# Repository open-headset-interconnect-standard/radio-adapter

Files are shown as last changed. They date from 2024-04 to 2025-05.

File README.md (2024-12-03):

# Open Source OHIS Radio Adapter(s?)
An open-source OHIS Radio Adapter.

As of 2024-07-17, this is a Work In Progress.

# Goals

1. Design a set of circuits that can be used to build OHIS compliant radio adapters.
2. Designs should be as simple as possible, but no simpler.
3. When laying out boards, keep as many parts through-hole as possible for ease of assembly.
4. There are two types of designs here:
    1. **General:** Has all the circuits required to work with any radio, that needs to be configured.
    2. **Radio Specific:** Trades Configurability for Simplicity.  Make a simpler device for a specific radio.

# Directory Structure

All KiCAD projects are in their own subdirectories off the git root.  Where it makes sense to do so, an additional layer of subdirectory may be used to group several projects together more obviously.

`/Documentation/` and `/docs/` are reserved for documentation source, and documentation output, respectively.

Everything in `/docs/` will be published on github Pages.

## Icom, Yaesu, Kenwood

As of 2024-04-04, I (@SmittyHalibut, Mark Smith, N6MTS) have submitted three schematics (only!) for VERY SIMPLE radio controllers for the Big Three.  A few notes about these:

* **I HAVE NOT TESTED THEM!**  There's no guaranty that they'll work, or even that they won't blow up your radio.  (It most likely won't blow up your radio. Probably.  I think.  It might.  It shouldn't.  Yeah, probably not.  But there's no telling.)
    * If you find a better way to do any of this, please submit a Pull Request, or at least an Issue with your idea.
* **YOU HAVE TO VERIFY PINOUTS MATCH YOUR RADIO!**  I've selected pinouts for most modern versions of these radios, but while researching this, it becomes obvious that older radios were not so consistent, even within a given manufacturer.  (Yaesu seems to be the worst at this, but they all do it.)
    * See [EB3GKE's Mic Pinout Reference](Yaesu/EB3GKE Mic Pinout Reference.pdf), it collects a lot of pinout information.  **BUT THEY GET RJ45 PINOUTS WRONG**.  As far as I could see, all (only most?) of their RJ45 pictures number pins 1 through 8 backwards.  OHIS's schematics are absolutely correct (verified against TIA-568 documents), so if the pinout for your radio looks VERY DIFFERENT than OHIS's pinouts, try reversing the pin numbers and see if thats closer.
* As of 2024-04-04, I've only done the schematics, and even then it's little more than throwing notes down "on paper."  I tried to cover:
    * Connector pinouts (see above).
    * Any electrical circuits required (mostly converting from OHIS's electret level to dynamic level for radios that want dynamic.)

As of 2024-04-25, I (still @SmittyHalibut) laid out the boards described above and had them fabricated.

* **I STILL HAVE NOT TESTED THEM!**

As of 2024-07-17, I (still me) am chatting with @gx1400 about this.  I'm going to send him some of the boards I ordered back in April and he'll help me test.

As of 2024-12-03, I (STILL me) am sending hardware to @gx1400 and a few others for testing.  These tests are covering:

* Yaesu:
  * :check: RJ45 8p8c
  * :check: RJ14 6p6c
  * :green_square: GX16
* Icom:
  * :green_square: RJ45 8p8c
  * :check: GX16
* Kenwood:
  * :check: RJ45 8p8c
  * :check: GX16

If you can test Yaesu GX16 or Icom RJ45, please reach out to me.  @SmittyHalibut on github, or on Discord.

# Parts

Electrical components, in recommended order of assembly:
* 1x 2x2 pin header right angle
* 1x 2x4 pin header right angle
* 1x 1k axial resistor
* 1x 6.2k axial resistor
* 2x 100R axial resistors
* 2x 10uF
* 1x 1k pot
* 1x 5381 (RJ45 with LED) for OHIS socket

Mechanical components, same as User kit:
* 4x M3 6mm screw
* 4x M3 10mm screw
* 4x M3 14mm brass stand-off
* 4x M3 3mm ABS stand-off
* 5x .1" jumper

PCBs in this repo:
* 2x Top-bottom panels
* 1x Main board
* 1x Shim board

Radio Specific parts, in recommended order of assembly:
* 1x Radio Specific Board
* 1x 3.5mm TRRS "headphone/speaker" connector
* Microphone connector.  Either one of:
  * 5380 (RJ45 with no LED) or 5381 (with LED) if its easier, but the LEDs aren't used.
  * GX16 connector, and GX16 riser board

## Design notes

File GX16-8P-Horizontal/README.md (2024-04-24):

# GX16-8P-Horizontal
A small board that allows the mounting of GX16-8P "8 pin round mic connectors" horizontally instead of vertically.

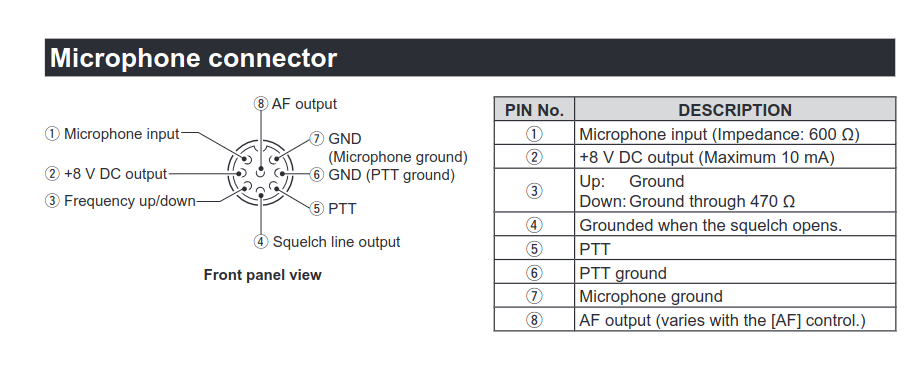
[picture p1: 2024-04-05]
Icom-GX16/Icom GX16-8p pinout.png

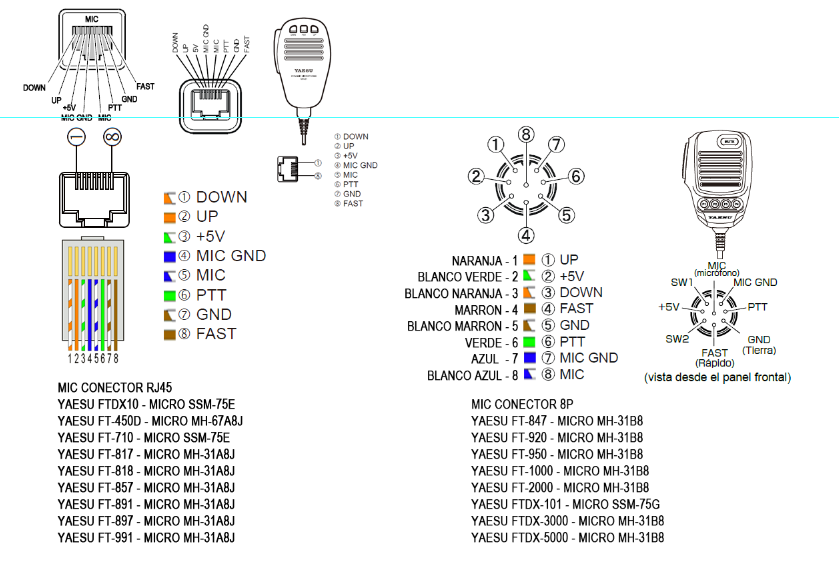
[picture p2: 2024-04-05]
Yaesu-RJ45/MicPinouts.png

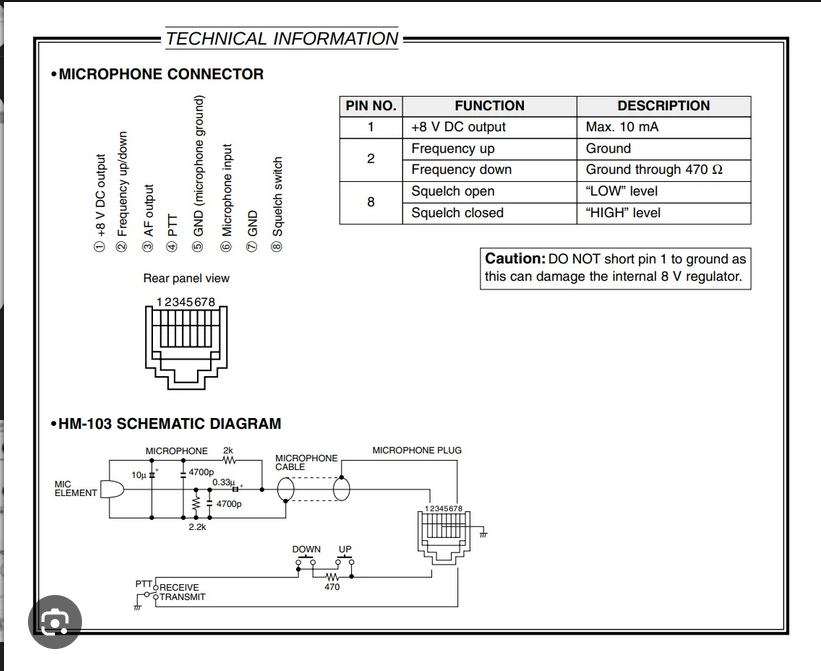
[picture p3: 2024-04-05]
Icom-RJ45/Icom RJ45 pinout.png

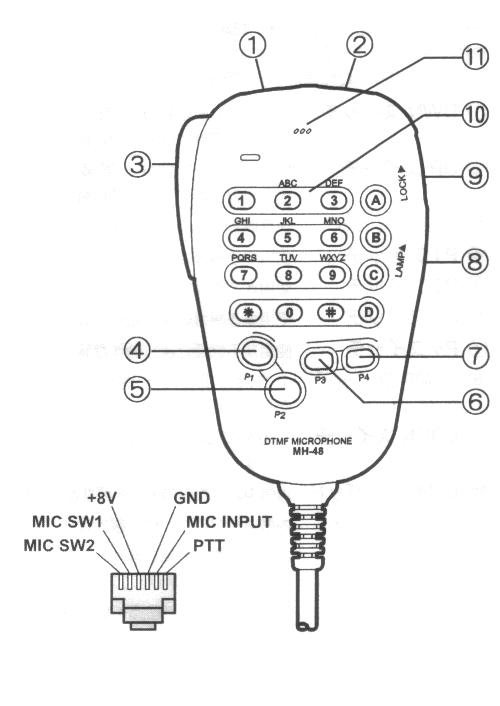
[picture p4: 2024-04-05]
Yaesu-6p6c/MH-48A6JA-1.jpg

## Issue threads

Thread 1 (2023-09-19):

Design Open Source Radio Adapter

SmittyHalibut, 2023-09-19:
Design a simple schematic and board layout for a generic Radio adapter that can be configured by the builder at build time for various different radios.

Keep it simple, make it a good DIY project.

CC-BY, credit to OHIS.  But allow commercial use and extension (read: not -NC and not -SA)

SmittyHalibut, 2024-04-04:
https://github.com/open-headset-interconnect-standard/radio-adapter

SmittyHalibut, 2024-04-18:
Started working on the board for Icom today (the simplest of the boards.)

I went down the SMT/Heatshrink path today, and I'm not happy where that ended up.  Instead, I think I'm going to go down a similar path that I did with https://github.com/open-headset-interconnect-standard/user-adapter/issues/1  where everything is throughhole, and physical construction is a stack of boards, and configuration is done with horizontal jumpers out the side of the stack.  (But it's dinner time now, so later...)

SmittyHalibut, 2024-04-22:
I got the Icom Radio Controller done sorta like the user adapter, then started working on the Kenwood.  While doing so, I realized that all the Radio Adapters are going to have, or not have, the same basic building blocks: mic interface for electret vs dynamic, speaker vs headphone, stereo vs mono.  The main difference between the different radios is the connector and pinout.

Rather than implement these building blocks multiple times on different boards for each manufacturer, I should put all the building blocks on a common board, make them jumper configurable, then make a separate board that just has the physical connections, and routes the pins to the correct signal.  The interface between the two boards is spec'd for the signals, not the pins.

So, that's what I started doing.  See commit 0f612d360049099635a8422bd952ba6b0dee2bb7

This is still very much a work in progress; I have to break to do some other things this week, but will get back to this.

SmittyHalibut, 2024-04-25:
I ordered prototype boards yesterday:
* Base Board
* Radio boards for:
  * Yaesu RJ45, GX16, and RJ12/6p6c (for Yaesu mobiles)
  * Kenwood RJ45, and GX16
  * Icom RJ45, and GX16
* GX16 riser board (to make it a right-angle connector)
* Top/Bottom panels

SmittyHalibut, 2024-12-03:
FINALLY got around to building some of these, and sending kits out to others to test.  I've already found some things I want to do differently.  See #2.

For now, I'll close this ticket and do all follow-up in #2.

Closed 2024-12-03.

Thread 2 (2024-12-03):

Changes for v1.1

SmittyHalibut, 2024-12-03:
Follow-up from #1 these are the changes I want to make.

ATLombardi, 2024-12-07:
I'm not sure how difficult this would be, but with how much clearance is underneath the GX16 it might be possible to lower it down and get away with using the existing standoffs. That might make connecting it to the radio board a little trickier though, since going down much further would put GX16 pin 4 very close to the radio board. Since the connection from pin 4 to the vertical slot is straight down anyway, that might not be a big issue...

ATLombardi, 2024-12-07:
As for the overall layout, I think it'd be interesting to do a version with a female GX16 socket and design the whole adapter to sit almost flush with the radio itself, similar to the PowerPole conversion blocks I've seen for the Yaesu FT-891 and other radios. I know the obvious issue here is that every radio has their mic port in a different place, but fewer cables means a neater setup and fewer things to forget when going portable or helping with an event.

SmittyHalibut, 2024-12-09:
> I'm not sure how difficult this would be, but with how much clearance is underneath the GX16 it might be possible to lower it down and get away with using the existing standoffs. That might make connecting it to the radio board a little trickier though, since going down much further would put GX16 pin 4 very close to the radio board. Since the connection from pin 4 to the vertical slot is straight down anyway, that might not be a big issue...

The vertical space is the concern. I lowered the GX16 as much as was convenient at the time not thinking about this problem. I'll spend some time lowering it as much as possible instead of as convenient. See what I can do.

SmittyHalibut, 2024-12-09:
> As for the overall layout, I think it'd be interesting to do a version with a female GX16 socket and design the whole adapter to sit almost flush with the radio itself, similar to the PowerPole conversion blocks I've seen for the Yaesu FT-891 and other radios. I know the obvious issue here is that every radio has their mic port in a different place, but fewer cables means a neater setup and fewer things to forget when going portable or helping with an event.

That is an interesting idea. I like it. My immediate questions are: I don't think PCB mount GX16s are common, or possibly available at all. I don't REMEMBER seeing them, but I also wasn't looking for them so maybe they are. Have you looked?

I'd also worry about the headphone/speaker connection. Physical spacing between the GX16 and 3.5mm won't be consistent across radios, so the 3.5mm will still need to be a cable for radios that don't provide audio out through the mic port.

But if we can find PCB mount female GX16, that would work pretty well for Icom radios (which do provide receive audio on the GX16.)

gx1400, 2024-12-17:
**Icom GX16 Radio Adapter notes**
Tested with an Icom IC7300 with a Heil Pro Set Elite-Ic (electret) headset.

- No issues with PTT

- Audio is brought in through the GX16, but without a cable plugged into the PHONES port on the front of an ICOM, the IC7300 speaker will not disable.

- Audio coming in through the 3.5mm audio jack is attenuated relative to the audio from the GX16 port (with no audio cable plugged into the GX16 adapter board.
    - I think the R6/R8 resistors are only needed if using GX16 audio? The IC7300 PHONE board has the 100ohm resistors inside the IC7300.

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

I'm confused a bit by the layout. Some install notes could be handy. This layout for the radio base board might need to be reviewed.

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

- Standoff notes
    - Radio adapter PCB screws with the hex standoff spacing.  I replaced the M3x10 mm screw with an M3x12 mm screw and added an M3 nut to adjust the offset a little bit.  Suggest some PCB spacers.
    - The spacers are overall too short. I used 20mm long M3 hex spacers. 18mm would probably work well.

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

- I did not think to remove the nut from the connector.  Suggest notes to do so.
- Schematic shows red X over R7 and R5, but the PCB has those two ref des on the silk screen.  Suggest moving the rest X or change the ref des
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

gx1400, 2024-12-17:
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

Maybe an Icom specific configured board should have some of the following notes:

- Do not install: C1, C2, RV2, R4
- Install jumper wire on J3 from pin 2 to pin 4
- Unsure about R7 & R5 on headphones

SmittyHalibut, 2024-12-17:
> Audio is brought in through the GX16, but without a cable plugged into the PHONES port on the front of an ICOM, the IC7300 speaker will not disable.

This is a known issue.  I'm not sure whether the built-in speaker can be disabled in software while still allowing audio out the GX16.  It might require a dummy-plug in the headphones port or something.

> Audio coming in through the 3.5mm audio jack is attenuated relative to the audio from the GX16 port (with no audio cable plugged into the GX16 adapter board. I think the R6/R8 resistors are only needed if using GX16 audio? The IC7300 PHONE board has the 100ohm resistors inside the IC7300.

The 100R resistors are bypassable.  That's what the jumpers on J6, pins 1-2, 3-4.  They short across the 100R resistors.  You need the 100R if you're feeding from a speaker output, and don't need them if feeding from a headphone output.  So putting jumpers on that side of the header shorts out the 100R series resistors.

Does that change the audio levels for you?

> I'm confused a bit by the layout. Some install notes could be handy. This layout for the radio base board might need to be reviewed.

And how...  Yes, this needs assembly instructions, which I haven't written yet.  I probably should have thrown together some notes before sending the hardware to y'all.

I'm all for changes to the board layout if it'll make it easier to understand what's going on.  Any specific suggestions? (other than what you've already presented here, that is.)

> Radio adapter PCB screws with the hex standoff spacing. I replaced the M3x10 mm screw with an M3x12 mm screw and added an M3 nut to adjust the offset a little bit. Suggest some PCB spacers.

M3x12mm: I came to that conclusion too.  I've updated the BOM.

Spacer: Already done, and almost ready to ship to me.
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

These are the same thickness as the radio-specific board and go on the other stand-offs to even them out.  Yes, I made sure the dog-bone would fit. :-)

> The spacers are overall too short. I used 20mm long M3 hex spacers. 18mm would probably work well.

Yeah, the stand-offs were sized for RJ45s; I didn't think about the GX16 being taller.

> Schematic shows red X over R7 and R5, but the PCB has those two ref des on the silk screen. Suggest moving the rest X or change the ref des

Good catch. That was the intent from the beginning, I just missed these.  Thanks.  Fixed.

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

That's exactly what the jumper header does.  Note the silkscreen on the board shows you the orientation to install a jumper to bypass the mic attenuation circuit.

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

Your jumpers are installed correctly (horizontally).  Does adjusting RV1 make a difference to your mic audio level?  Does removing those components change anything?

Or, are you just saying because they will NEVER be needed, don't bother populating them and just hard jumper the board instead?

That's actually a compelling argument:  Since the radio-specific board is soldered in place, any given kit will only ever work in one radio configuration.  Having it be reconfigurable doesn't make as much sense as it does on the User Adapter.

SmittyHalibut, 2024-12-17:
Bah. @gx1400 ^^  Forgot to mention you. Sorry.

gx1400, 2024-12-17:
> > Audio is brought in through the GX16, but without a cable plugged into the PHONES port on the front of an ICOM, the IC7300 speaker will not disable.
>
> This is a known issue. I'm not sure whether the built-in speaker can be disabled in software while still allowing audio out the GX16. It might require a dummy-plug in the headphones port or something.

I feel like maybe those 100ohm resistors should live on the GX16 add-on board, then get disconnected (to use the ones that are inside of the IC7300) when an audio cable is inserted.

I think for the ICOM IC7300, I'd recommend cutting the trace (or putting a ohm jumper pad there) so that it needs to the headphone audio cable for audio.

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

I finally figured that out last night.  It's just some clever layout that's hard to follow.

It does change the audio level, But maybe it's the 100ohm resistors in the IC7300 vs the lack thereof over the GX16 audio path that's throwing me for a loop.

> Spacer: Already done, and almost ready to ship to me. ![image](https://private-user-images.githubusercontent.com/497398/396599900-60df5b04-bdd5-45bd-bb56-a667b9458f8d.png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)
>
> These are the same thickness as the radio-specific board and go on the other stand-offs to even them out. Yes, I made sure the dog-bone would fit. :-)

Looks nice!

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
SmittyHalibut, 2024-12-17:
> I feel like maybe those 100ohm resistors should live on the GX16 add-on board, then get disconnected (to use the ones that are inside of the IC7300) when an audio cable is inserted.
>
> If not, I think for the ICOM IC7300, I'd recommend cutting the trace (or putting a ohm jumper pad there) so that it needs to the headphone audio cable for audio.

I remembered now.  I'm not sure that all Icom radios put out audio on GX16.  I know its common with modern gear, but I don't know how universal that has been over the years.  Similarly, I'm pretty sure that not all radios have Headphones output, some might only have Speaker.  The 100R are required there.

So the question isn't: What's needed to support THIS PARTICULAR ICOM, but what's needed to support ALL Icoms?  I don't think it's a good idea to limit the options.

> I finally figured that out last night. It's just some clever layout that's hard to follow.

Yeah, it took me a bit to figure it out again today.  I could draw that better, that's for sure.

> It does change the audio level, But maybe it's the 100ohm resistors in the IC7300 vs the lack thereof over the GX16 audio path that's throwing me for a loop.

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

I think the right answer here is to keep the header outline on the board, but document how to assemble it hard wired for a given config so the jumpers aren't needed.  And say things like: "If you configure for electret, you're bypassing this whole circuit so you can just leave those parts off the board if you want."

But I do want to keep the configuration options available.

> I think the README for any specific radio or family of radios could tell you (and show you) which jumpers and components to install where.

Agreed.  The documentation on these prototypes I sent you was ... well, "lacking" is too kind a word.  "Entirely non-existent" is more accurate.

> Removing the right angle connectors and pin jumpers might help bring down bom cost a bit too

They are a tiny fraction of the BOM cost.  I'd keep them in the kit, but document how to not use them if you don't want to.

gx1400, 2024-12-20:
For Yaesu RJ45 kits - the kits you shipped have one RJ45 with LED leads, the other without. If plan it to sell kits with one of each, be sure to emphasize that the two RJ45s are different and that the LED should be noted and installed in the correct location

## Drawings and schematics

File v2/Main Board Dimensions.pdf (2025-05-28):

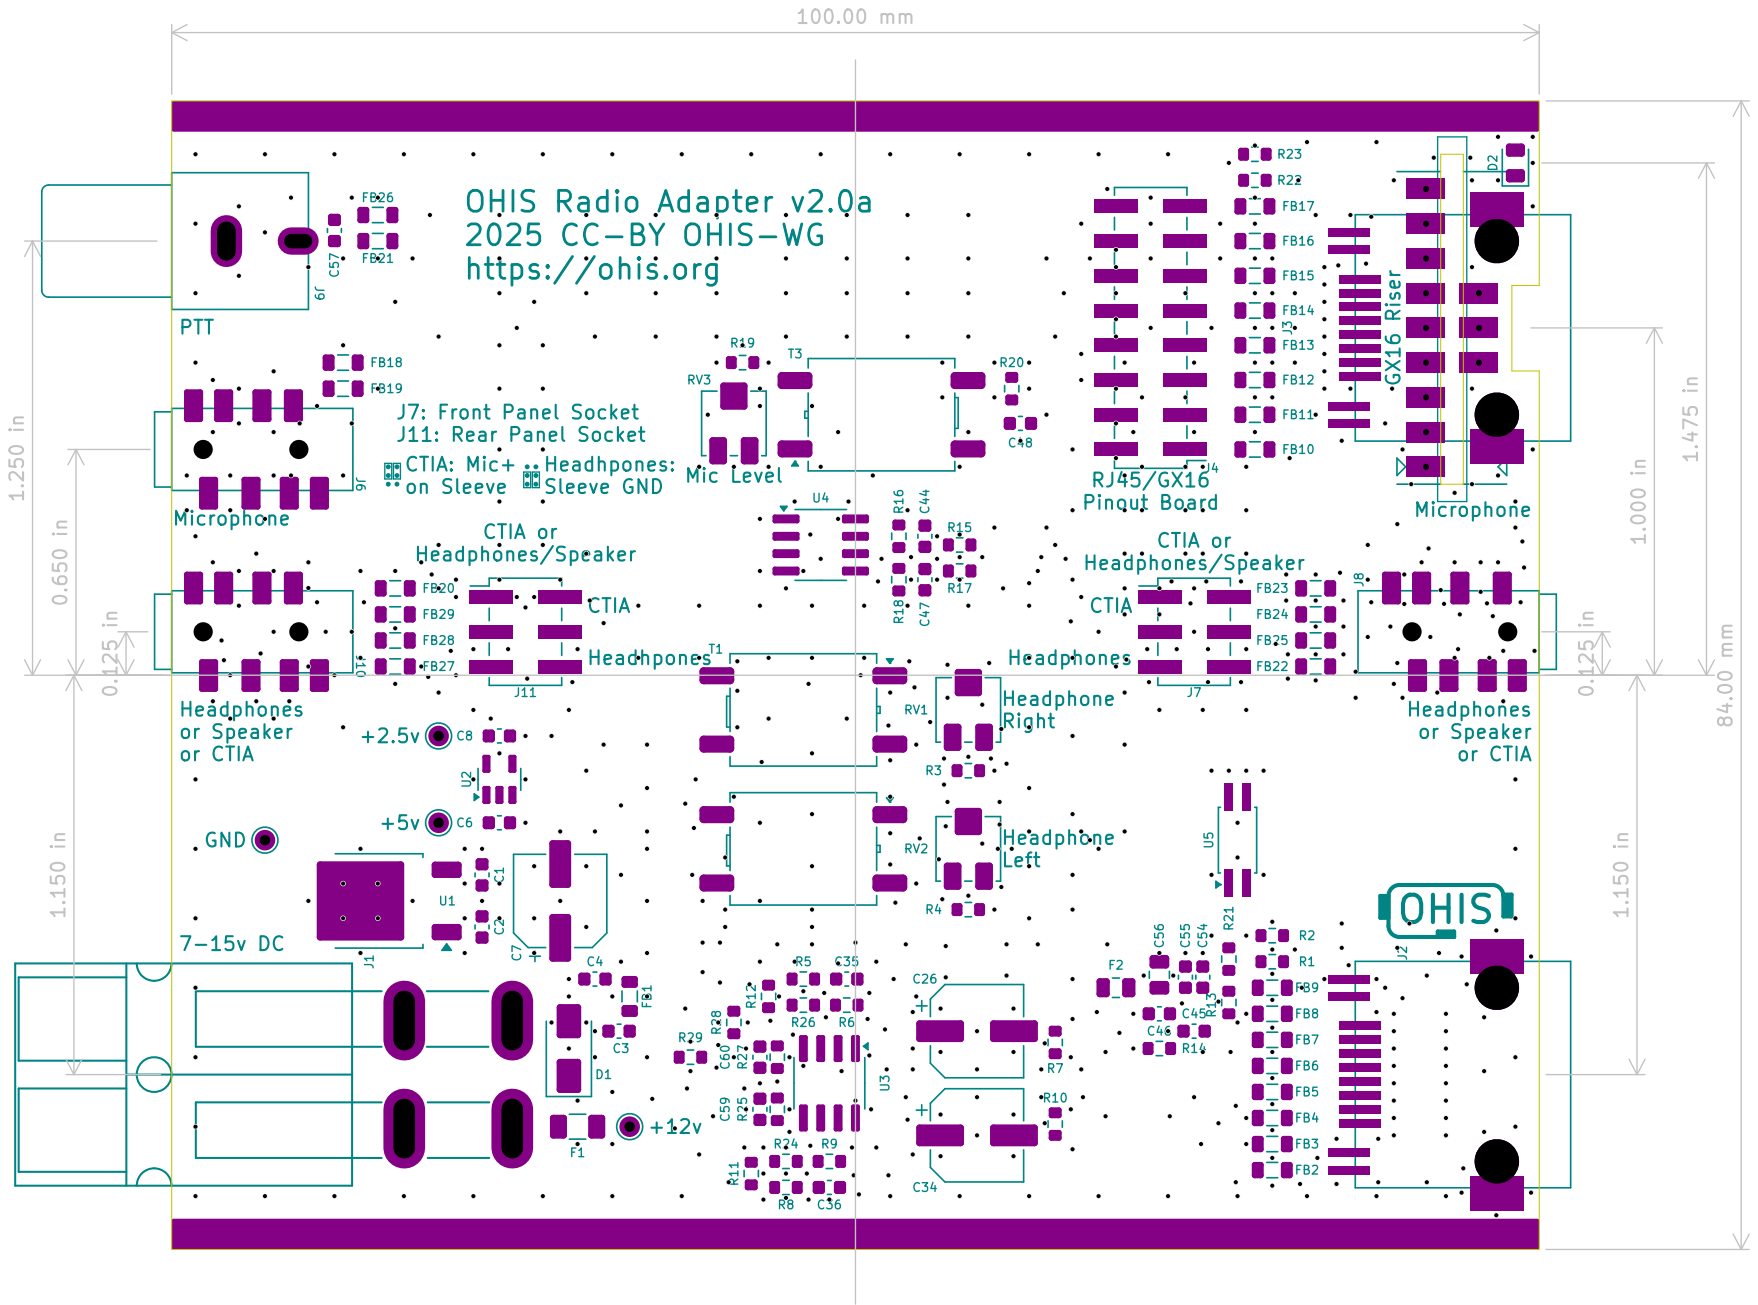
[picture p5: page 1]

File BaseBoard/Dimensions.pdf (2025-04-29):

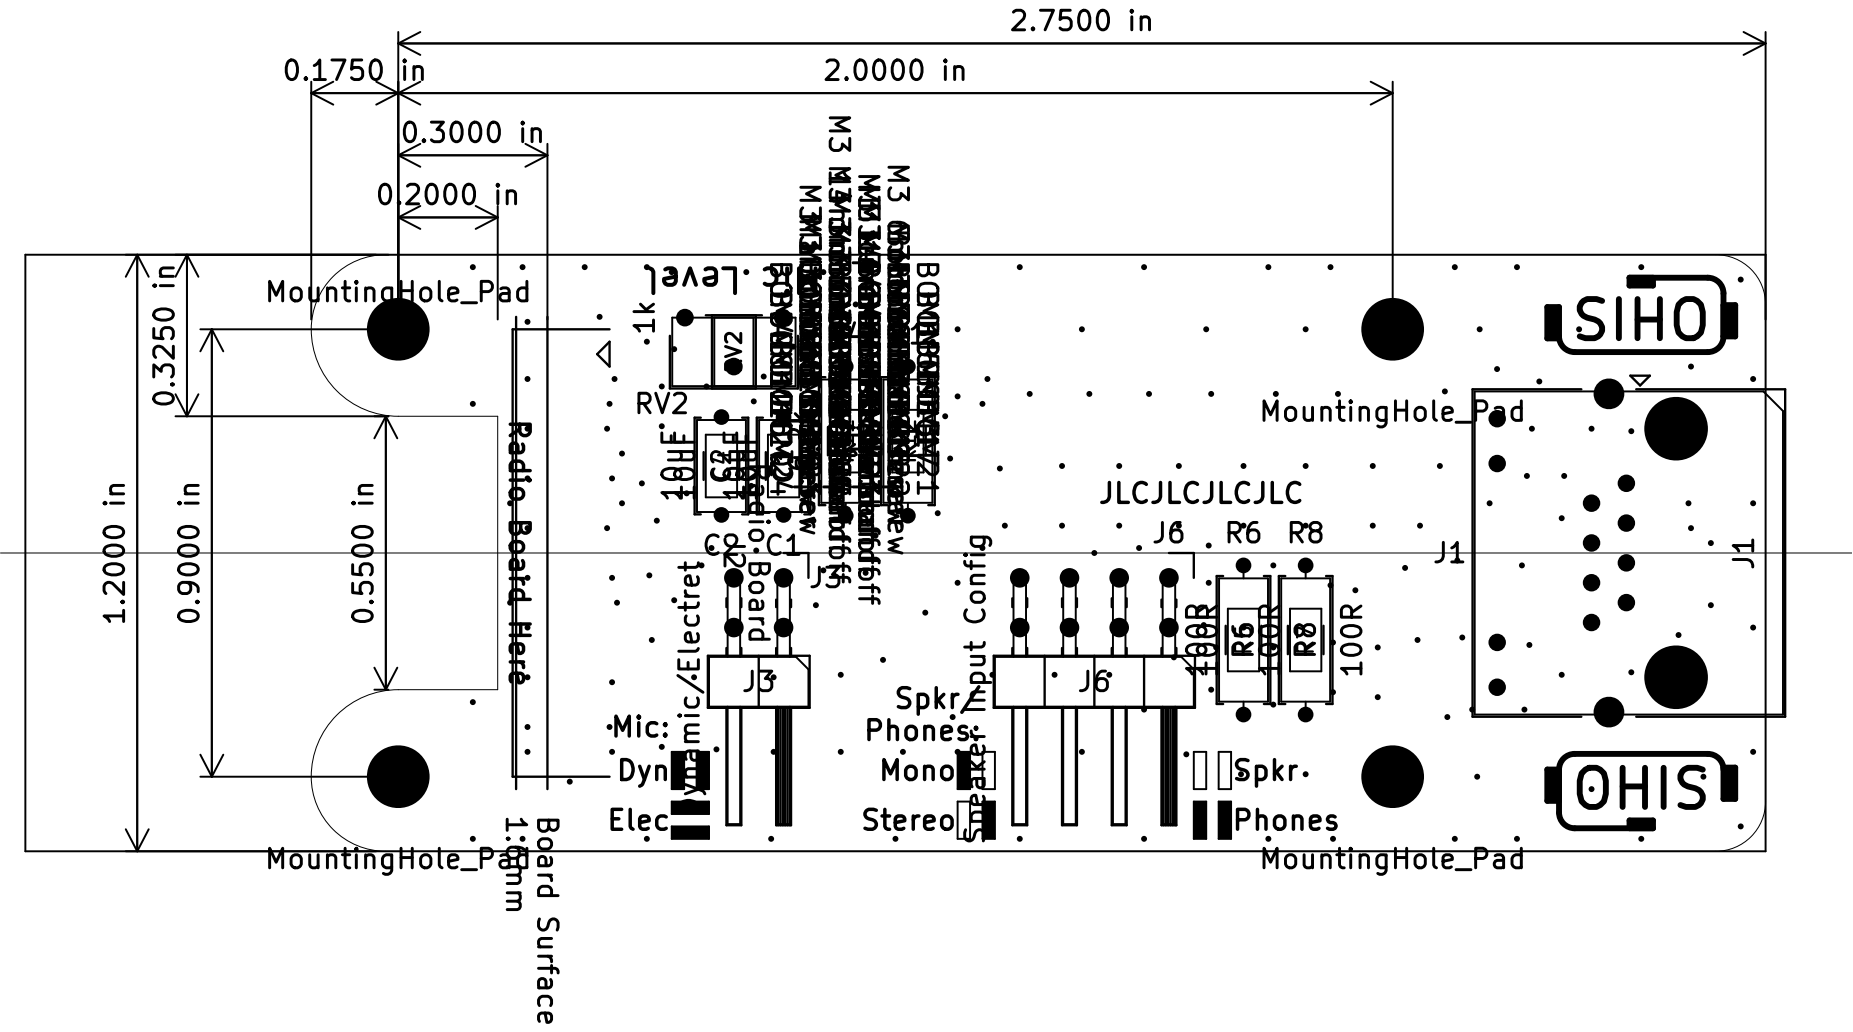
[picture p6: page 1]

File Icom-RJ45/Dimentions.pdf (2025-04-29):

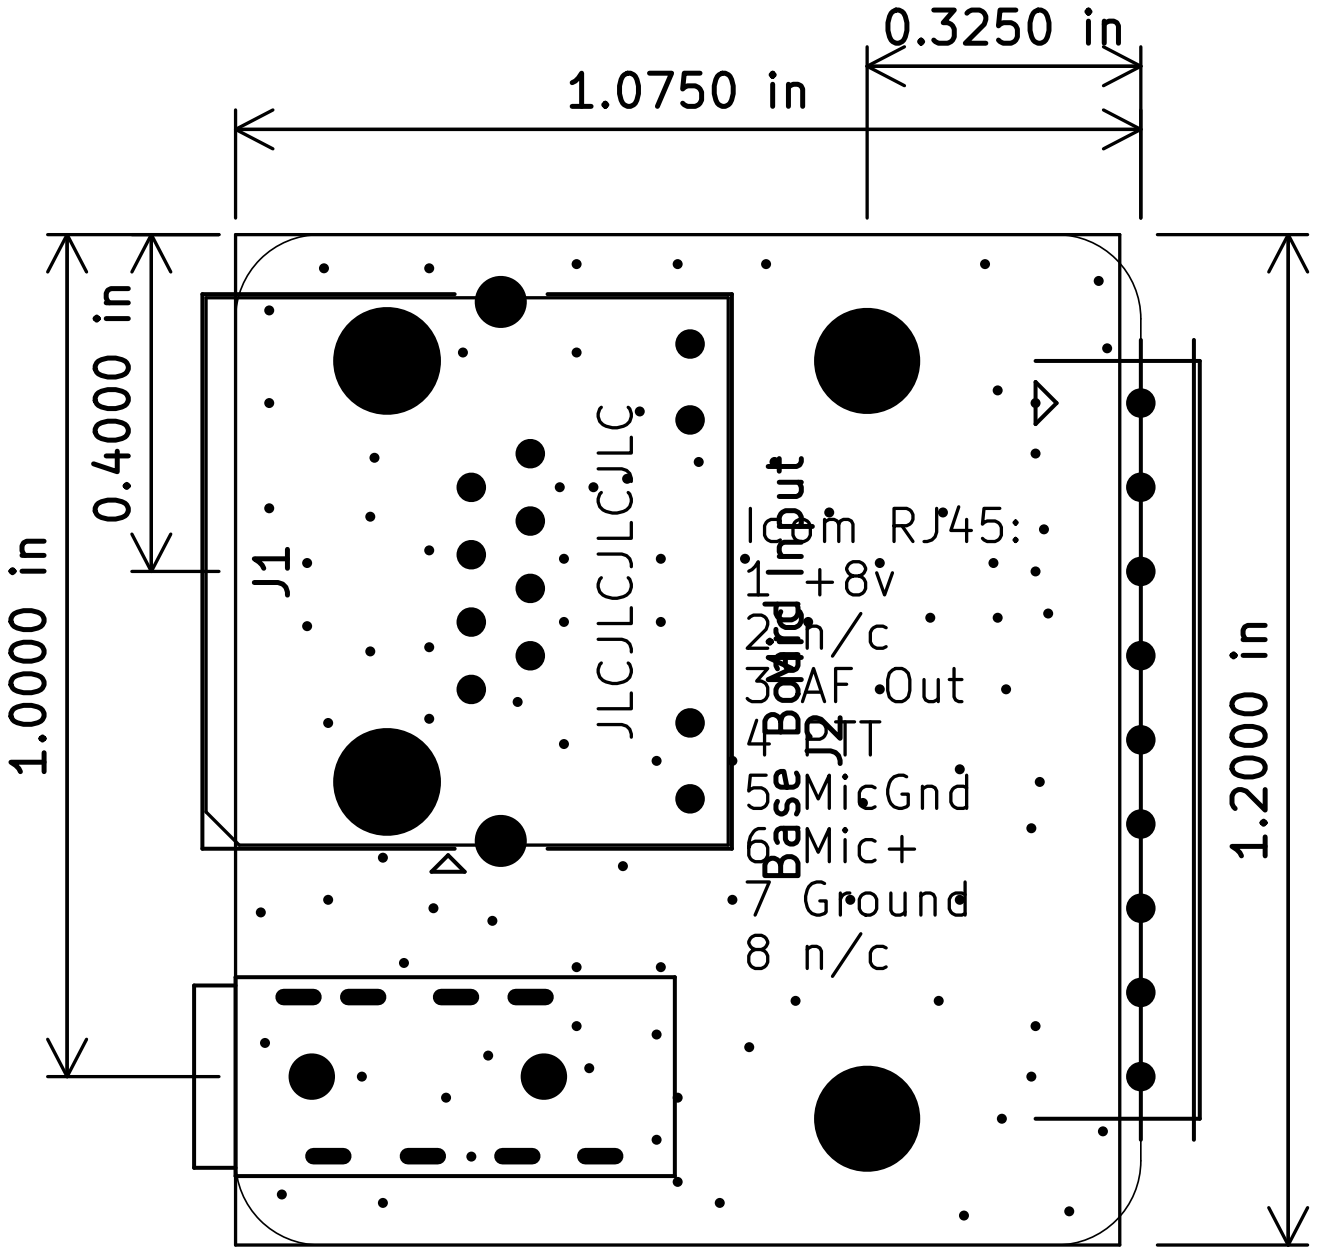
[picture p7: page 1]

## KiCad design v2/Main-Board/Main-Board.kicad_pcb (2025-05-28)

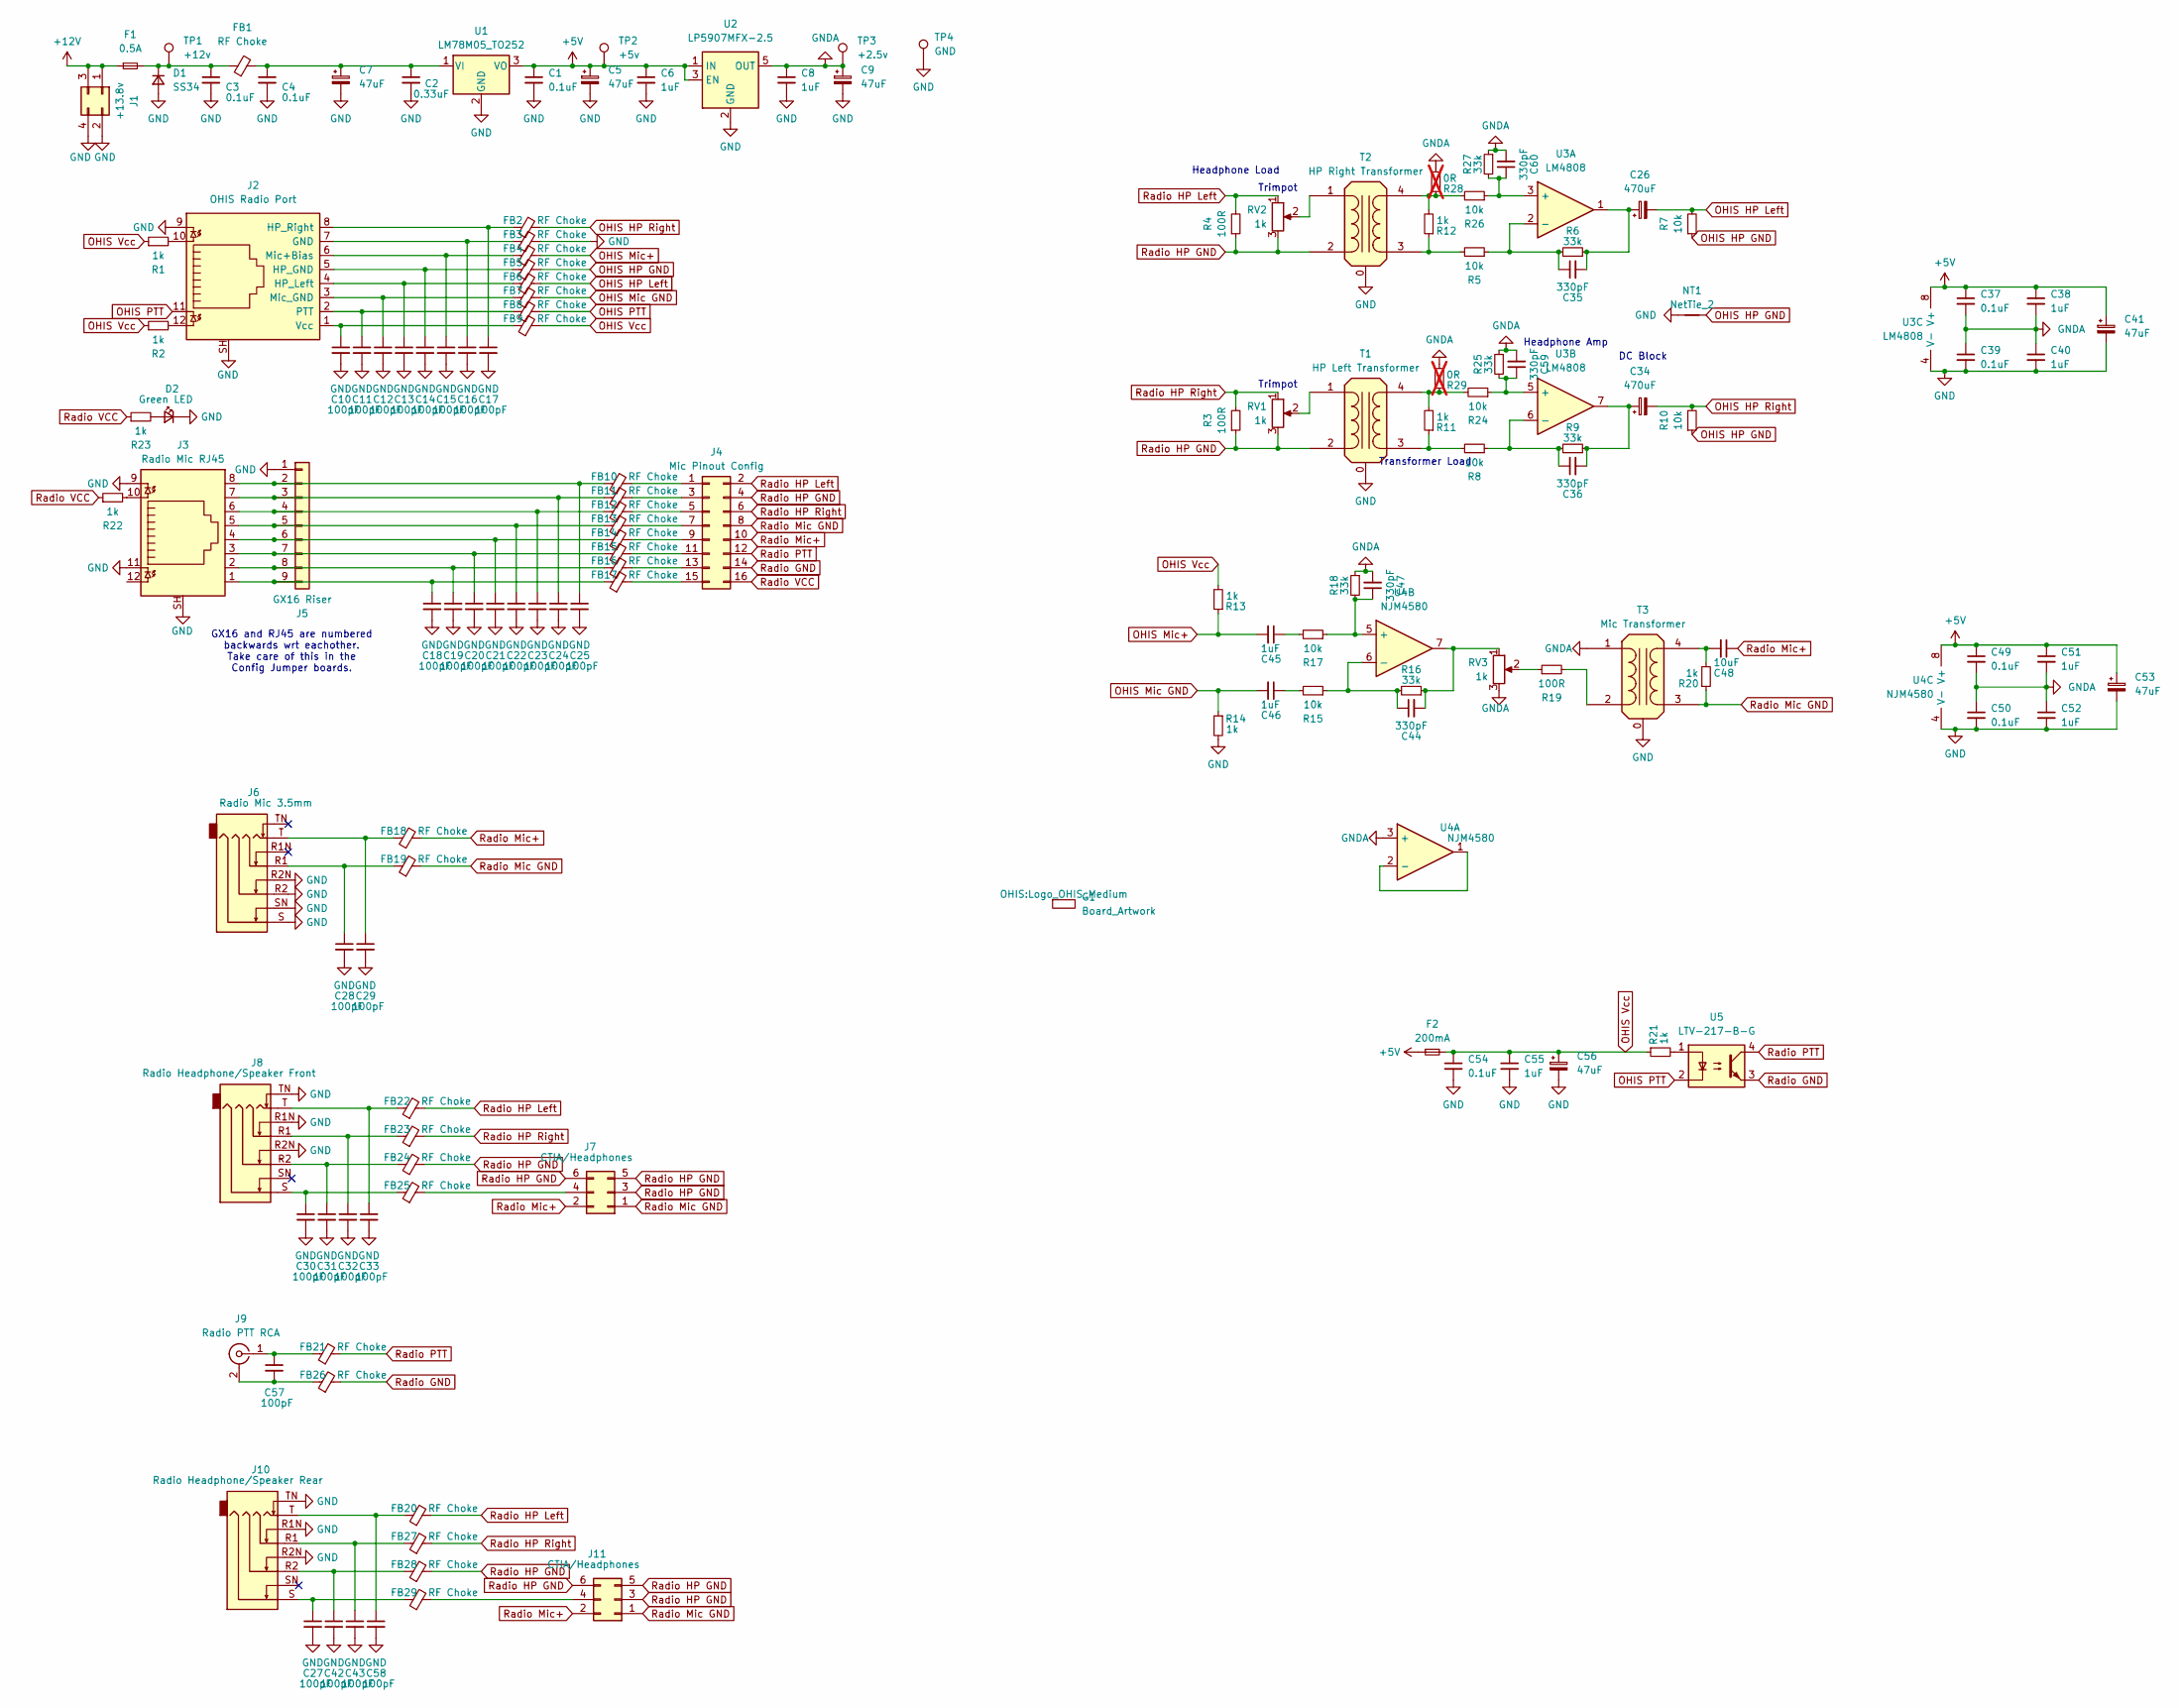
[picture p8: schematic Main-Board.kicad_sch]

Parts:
C1, C3, C4, C37, C39, C49, C50, C54: 0.1uF; C_0603_1608Metric; LCSC C14663
C2: 0.33uF; C_0603_1608Metric; LCSC C1615
C5, C9, C41, C53, C56: 47uF; C_0805_2012Metric; LCSC C16780
C6, C8, C38, C40, C45, C46, C51, C52, C55: 1uF; C_0603_1608Metric; LCSC C15849
C7: 47uF; CP_Elec_6.3x5.8; LCSC C401754
C10, C11, C12, C13, C14, C15, C16, C17, C18, C19, C20, C21, C22, C23, C24, C25, C27, C28, C29, C30, C31, C32, C33, C42, C43, C57, C58: 100pF; C_0603_1608Metric; LCSC C14858
C26, C34: 470uF; CP_Elec_6.3x7.7; LCSC C344072
C35, C36, C44, C47, C59, C60: 330pF; C_0603_1608Metric; LCSC C1664
C48: 10uF; C_0603_1608Metric; LCSC C19702
D1: SS34; D_SMA; LCSC C8678
D2: Green LED; LED_0805_2012Metric; LCSC C2297
F1: 0.5A; Fuse_1206_3216Metric; LCSC C720075
F2: 200mA; Fuse_0805_2012Metric; LCSC C516070
FB1, FB2, FB3, FB4, FB5, FB6, FB7, FB8, FB9, FB10, FB11, FB12, FB13, FB14, FB15, FB16, FB17, FB18, FB19, FB20, FB21, FB22, FB23, FB24, FB25, FB26, FB27, FB28, FB29: RF Choke; L_0805_2012Metric; LCSC C1017
G1: Board_Artwork; Logo_OHIS_Medium
J1: +13.8v; AndersonPP45-Dual
J2: OHIS Radio Port; Conn_RJ45_SMT_Amphenol-RJCSE-538X; LCSC C5384260
J3: Radio Mic RJ45; Conn_RJ45_SMT_Amphenol-RJCSE-538X; LCSC C5384260
J4: Mic Pinout Config; PinHeader_2x08_P2.54mm_Vertical_SMD; LCSC C32713288
J5: GX16 Riser; Conn_B2B-RA_2.54mm_9pin_Full-Slot
J6: Radio Mic 3.5mm; Conn_3.5mm-PJ-393-8_SMT-C668609; LCSC C668609
J7, J11: CTIA/Headphones; PinHeader_2x03_P2.54mm_Vertical_SMD; LCSC C32713283
J8: Radio Headphone/Speaker Front; Conn_3.5mm-PJ-393-8_SMT-C668609; LCSC C668609
J9: Radio PTT RCA; Conn_RCA_Kobiconn_156-009x-E
J10: Radio Headphone/Speaker Rear; Conn_3.5mm-PJ-393-8_SMT-C668609; LCSC C668609
NT1: NetTie_2; NetTie-2_SMD_Pad0.5mm
R1, R2, R11, R12, R13, R14, R20, R21, R22, R23: 1k; R_0603_1608Metric; LCSC C21190
R3, R4, R19: 100R; R_0603_1608Metric; LCSC C22775
R5, R7, R8, R10, R15, R17, R24, R26: 10k; R_0603_1608Metric; LCSC C25804
R6, R9, R16, R18, R25, R27: 33k; R_0603_1608Metric; LCSC C4216
R28, R29: 0R; R_0603_1608Metric; LCSC C21190; not fitted
RV1, RV2, RV3: 1k; Potentiometer_Bourns_3314J_Vertical; LCSC C124640
T1: HP Left Transformer; Transformer_ED8_4-Lead_10.5x8mm_P5mm; LCSC C840532
T2: HP Right Transformer; Transformer_ED8_4-Lead_10.5x8mm_P5mm; LCSC C840532
T3: Mic Transformer; Transformer_ED8_4-Lead_10.5x8mm_P5mm; LCSC C840532
TP1: +12v; TestPoint_THTPad_D1.5mm_Drill0.7mm
TP2: +5v; TestPoint_THTPad_D1.5mm_Drill0.7mm
TP3: +2.5v; TestPoint_THTPad_D1.5mm_Drill0.7mm
TP4: GND; TestPoint_THTPad_D1.5mm_Drill0.7mm
U1: LM78M05_TO252; TO-252-2; LCSC C58069
U2: LP5907MFX-2.5; SOT-23-5; LCSC C165132
U3: LM4808; SOP-8_3.76x4.96mm_P1.27mm; LCSC C910863
U4: NJM4580; SOP-8_3.76x4.96mm_P1.27mm; LCSC C3000516
U5: LTV-217-B-G; SO-4_4.4x2.3mm_P1.27mm; LCSC C115450

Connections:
+5V: C1.1, C5.1, C6.1, C37.1, C38.1, C41.1, C49.1, C51.1, C53.1, F2.1, TP2.1, U1.3 (VO), U2.1 (IN), U2.3 (EN), U3.8 (V+), U4.8 (V+)
+12V: F1.1, J1.1, J1.3
GND: C1.2, C2.2, C3.2, C4.2, C5.2, C6.2, C7.2, C8.2, C9.2, C10.2, C11.2, C12.2, C13.2, C14.2, C15.2, C16.2, C17.2, C18.2, C19.2, C20.2, C21.2, C22.2, C23.2, C24.2, C25.2, C27.2, C28.2, C29.2, C30.2, C31.2, C32.2, C33.2, C39.2, C40.2, C41.2, C42.2, C43.2, C50.2, C52.2, C53.2, C54.2, C55.2, C56.2, C58.2, D1.2 (A), D2.1 (K), FB3.2, J1.2, J1.4, J2.9, J2.SH, J3.9, J3.11, J3.SH, J5.1, J6.R2, J6.R2N, J6.S, J6.SN, J8.R1N, J8.R2N, J8.TN, J10.R1N, J10.R2N, J10.TN, NT1.1, R14.2, T1.0, T2.0, T3.0, TP4.1, U1.2 (GND), U2.2 (GND), U3.4 (V-), U4.4 (V-)
GNDA: C8.1, C9.1, C37.2, C38.2, C39.1, C40.1, C47.2, C49.2, C50.1, C51.2, C52.1, C59.2, C60.2, R18.1, R25.1, R27.1, R28.2, R29.2, RV3.3, T3.1 (AA), TP3.1, U2.5 (OUT), U4.3 (+)
unnamed: C26.1, C35.2, R6.1, U3.1
unnamed: C27.1, FB29.1, J10.S
unnamed: C28.1, FB19.1, J6.R1
unnamed: C29.1, FB18.1, J6.T
unnamed: C30.1, FB25.1, J8.S
unnamed: C31.1, FB24.1, J8.R2
unnamed: C32.1, FB23.1, J8.R1
unnamed: C33.1, FB22.1, J8.T
unnamed: C34.1, C36.2, R9.1, U3.7
unnamed: C42.1, FB28.1, J10.R2
unnamed: C43.1, FB27.1, J10.R1
unnamed: C44.2, R16.1, RV3.1, U4.7
unnamed: C45.1, R17.2
unnamed: C46.1, R15.2
unnamed: C58.1, FB20.1, J10.T
unnamed: C3.1, D1.1 (K), F1.2, FB1.1, TP1.1
unnamed: D2.2 (A), R23.2
unnamed: C16.1, FB3.1, J2.7 (GND)
unnamed: C14.1, FB5.1, J2.5 (HP_GND)
unnamed: C13.1, FB6.1, J2.4 (HP_Left)
unnamed: C17.1, FB2.1, J2.8 (HP_Right)
unnamed: C15.1, FB4.1, J2.6 (Mic+Bias)
unnamed: C12.1, FB7.1, J2.3 (Mic_GND)
unnamed: C11.1, FB8.1, J2.2 (PTT)
unnamed: J2.10, R1.2
unnamed: J2.12, R2.2
unnamed: C10.1, FB9.1, J2.1 (Vcc)
unnamed: J3.10, R22.2
unnamed: FB10.2, J4.1
unnamed: FB11.2, J4.3
unnamed: FB12.2, J4.5
unnamed: FB13.2, J4.7
unnamed: FB14.2, J4.9
unnamed: FB15.2, J4.11
unnamed: FB16.2, J4.13
unnamed: FB17.2, J4.15
unnamed: C25.1, FB10.1, J3.8, J5.2
unnamed: C24.1, FB11.1, J3.7, J5.3
unnamed: C23.1, FB12.1, J3.6, J5.4
unnamed: C22.1, FB13.1, J3.5, J5.5
unnamed: C21.1, FB14.1, J3.4, J5.6
unnamed: C20.1, FB15.1, J3.3, J5.7
unnamed: C19.1, FB16.1, J3.2, J5.8
unnamed: C18.1, FB17.1, J3.1, J5.9
unnamed: FB25.2, J7.4
unnamed: C57.2, FB26.1, J9.2 (Ext)
unnamed: C57.1, FB21.1, J9.1 (In)
unnamed: FB29.2, J11.4
unnamed: R19.1, RV3.2
unnamed: R21.2, U5.1
unnamed: RV1.2, T1.1 (AA)
unnamed: R8.2, R11.1, T1.3 (SA)
unnamed: R11.2, R24.2, R29.1, T1.4 (SB)
unnamed: RV2.2, T2.1 (AA)
unnamed: R5.2, R12.1, T2.3 (SA)
unnamed: R12.2, R26.2, R28.1, T2.4 (SB)
unnamed: R19.2, T3.2 (AB)
unnamed: C48.2, R20.2, T3.4 (SB)
unnamed: C2.1, C4.1, C7.1, FB1.2, U1.1 (VI)
unnamed: C60.1, R26.1, R27.2, U3.3 (+)
unnamed: C35.1, R5.1, R6.2, U3.2 (-)
unnamed: C59.1, R24.1, R25.2, U3.5 (+)
unnamed: C36.1, R8.1, R9.2, U3.6 (-)
unnamed: U4.1, U4.2 (-)
unnamed: C47.1, R17.1, R18.2, U4.5 (+)
unnamed: C44.1, R15.1, R16.2, U4.6 (-)
OHIS HP GND: FB5.2, NT1.2, R7.1, R10.1
OHIS HP Left: C26.2, FB6.2, R7.2
OHIS HP Right: C34.2, FB2.2, R10.2
OHIS Mic GND: C46.2, FB7.2, R14.1
OHIS Mic+: C45.2, FB4.2, R13.1
OHIS PTT: FB8.2, J2.11, U5.2
OHIS Vcc: C54.1, C55.1, C56.1, F2.2, FB9.2, R1.1, R2.1, R13.2, R21.1
Radio GND: FB26.2, J4.14, U5.3
Radio HP GND: FB24.2, FB28.2, J4.4, J7.3, J7.5, J7.6, J11.3, J11.5, J11.6, R3.1, R4.1, RV1.3, RV2.3, T1.2 (AB), T2.2 (AB)
Radio HP Left: FB20.2, FB22.2, J4.2, R4.2, RV2.1
Radio HP Right: FB23.2, FB27.2, J4.6, R3.2, RV1.1
Radio Mic GND: FB19.2, J4.8, J7.1, J11.1, R20.1, T3.3 (SA)
Radio Mic+: C48.1, FB18.2, J4.10, J7.2, J11.2
Radio PTT: FB21.2, J4.12, U5.4
Radio VCC: J4.16, R22.1, R23.1

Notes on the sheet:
Trimpot
Headphone Load
Headphone Amp
DC Block
GX16 and RJ45 are numbered backwards wrt eachother. Take care of this in the Config Jumper boards.
Transformer Load

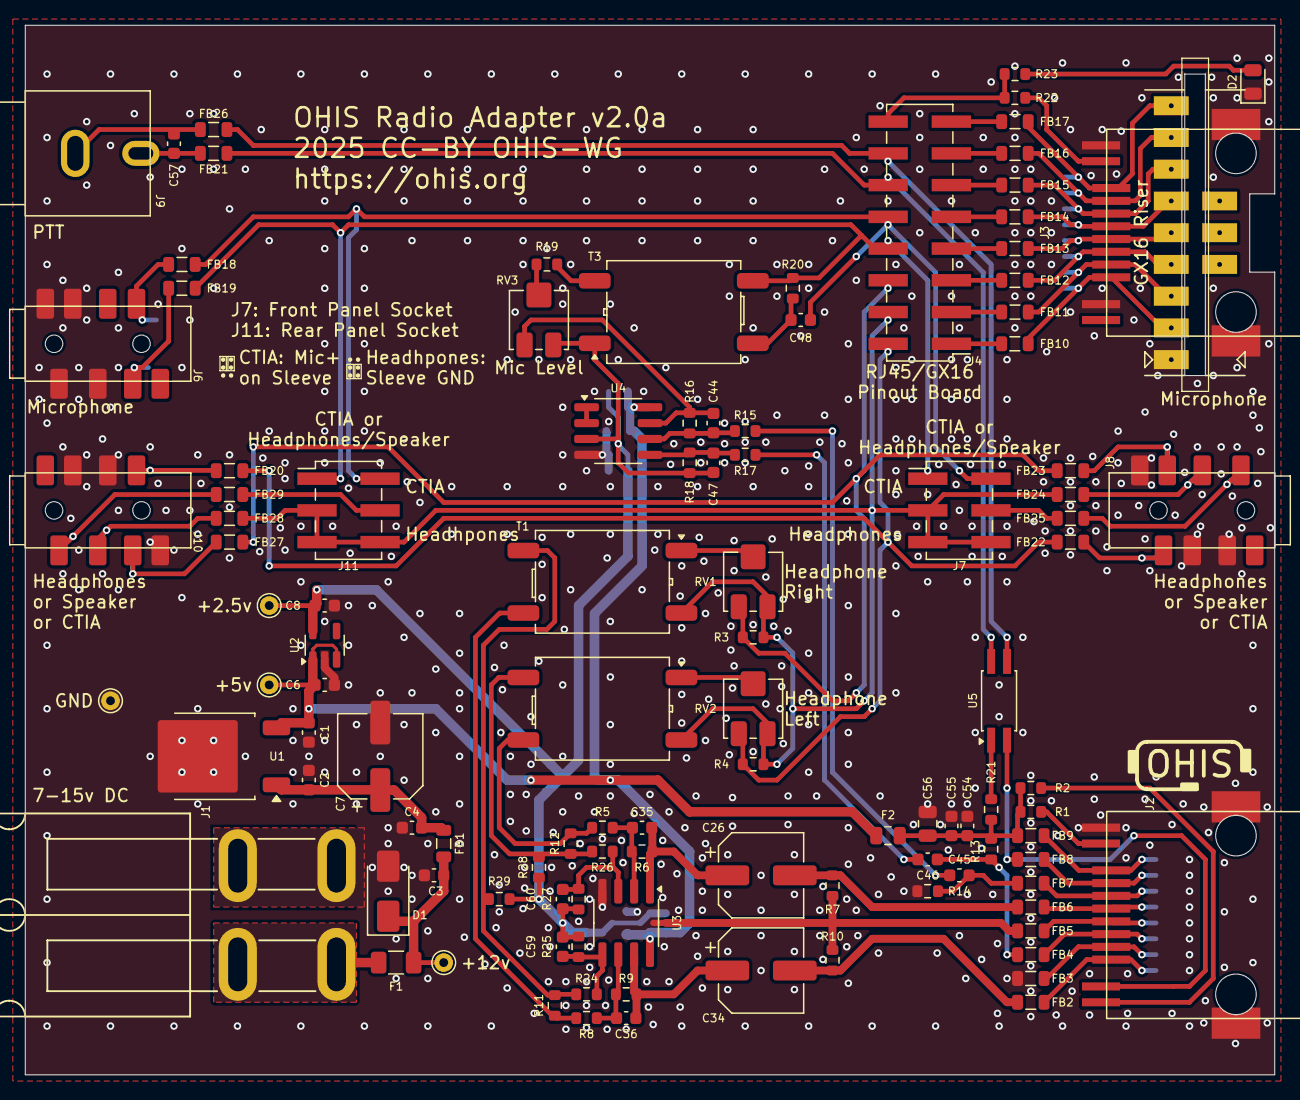
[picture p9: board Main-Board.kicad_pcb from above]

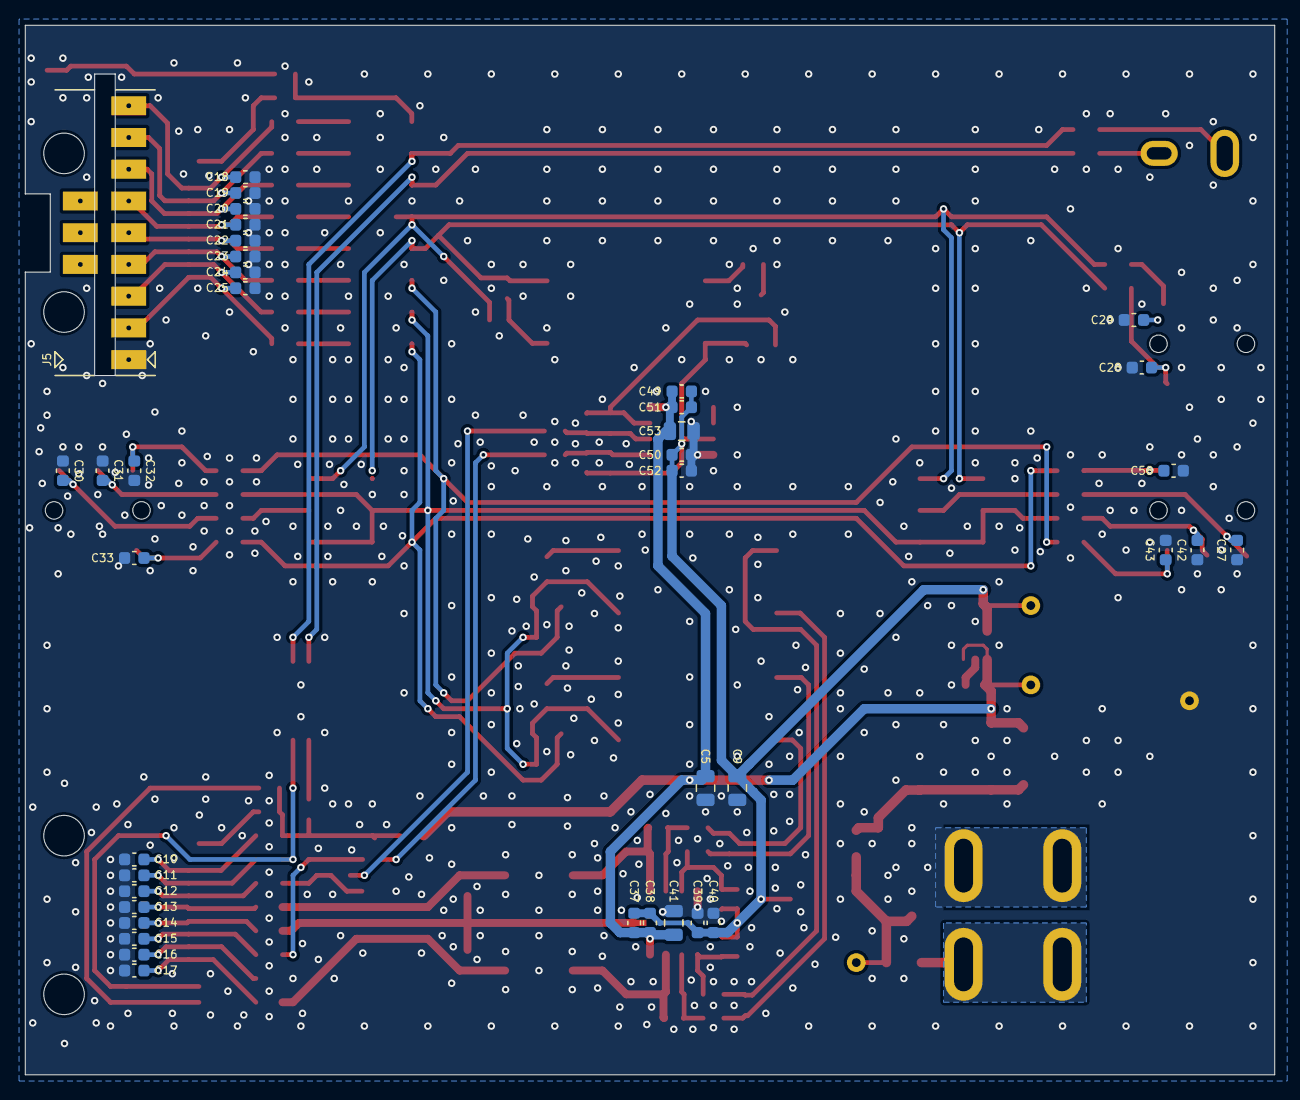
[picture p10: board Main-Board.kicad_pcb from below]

Board: 2 copper layers, 100.0 x 84.0 mm, 150 parts (39 on the bottom side), 85 nets.

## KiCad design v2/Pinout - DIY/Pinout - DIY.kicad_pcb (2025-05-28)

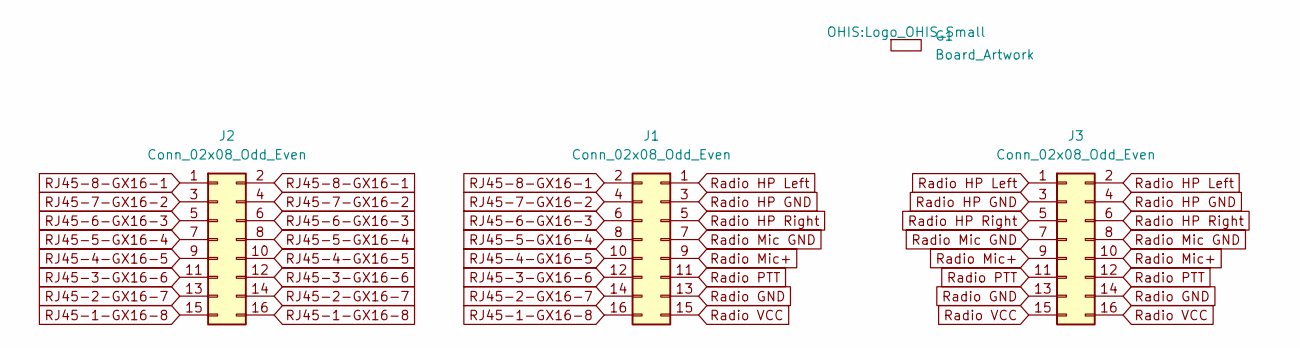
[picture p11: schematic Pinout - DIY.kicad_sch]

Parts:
G1: Board_Artwork; Logo_OHIS_Small
J1, J2, J3: Conn_02x08_Odd_Even; PinSocket_2x08_P2.54mm_Vertical

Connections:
RJ45-1-GX16-8: J1.16, J2.15, J2.16
RJ45-2-GX16-7: J1.14, J2.13, J2.14
RJ45-3-GX16-6: J1.12, J2.11, J2.12
RJ45-4-GX16-5: J1.10, J2.9, J2.10
RJ45-5-GX16-4: J1.8, J2.7, J2.8
RJ45-6-GX16-3: J1.6, J2.5, J2.6
RJ45-7-GX16-2: J1.4, J2.3, J2.4
RJ45-8-GX16-1: J1.2, J2.1, J2.2
Radio GND: J1.13, J3.13, J3.14
Radio HP GND: J1.3, J3.3, J3.4
Radio HP Left: J1.1, J3.1, J3.2
Radio HP Right: J1.5, J3.5, J3.6
Radio Mic GND: J1.7, J3.7, J3.8
Radio Mic+: J1.9, J3.9, J3.10
Radio PTT: J1.11, J3.11, J3.12
Radio VCC: J1.15, J3.15, J3.16

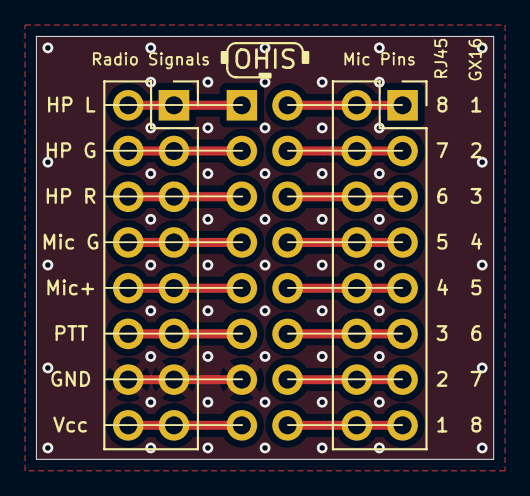
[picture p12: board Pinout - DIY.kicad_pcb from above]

Board: 2 copper layers, 25.4 x 23.5 mm, 4 parts (1 on the bottom side), 16 nets.

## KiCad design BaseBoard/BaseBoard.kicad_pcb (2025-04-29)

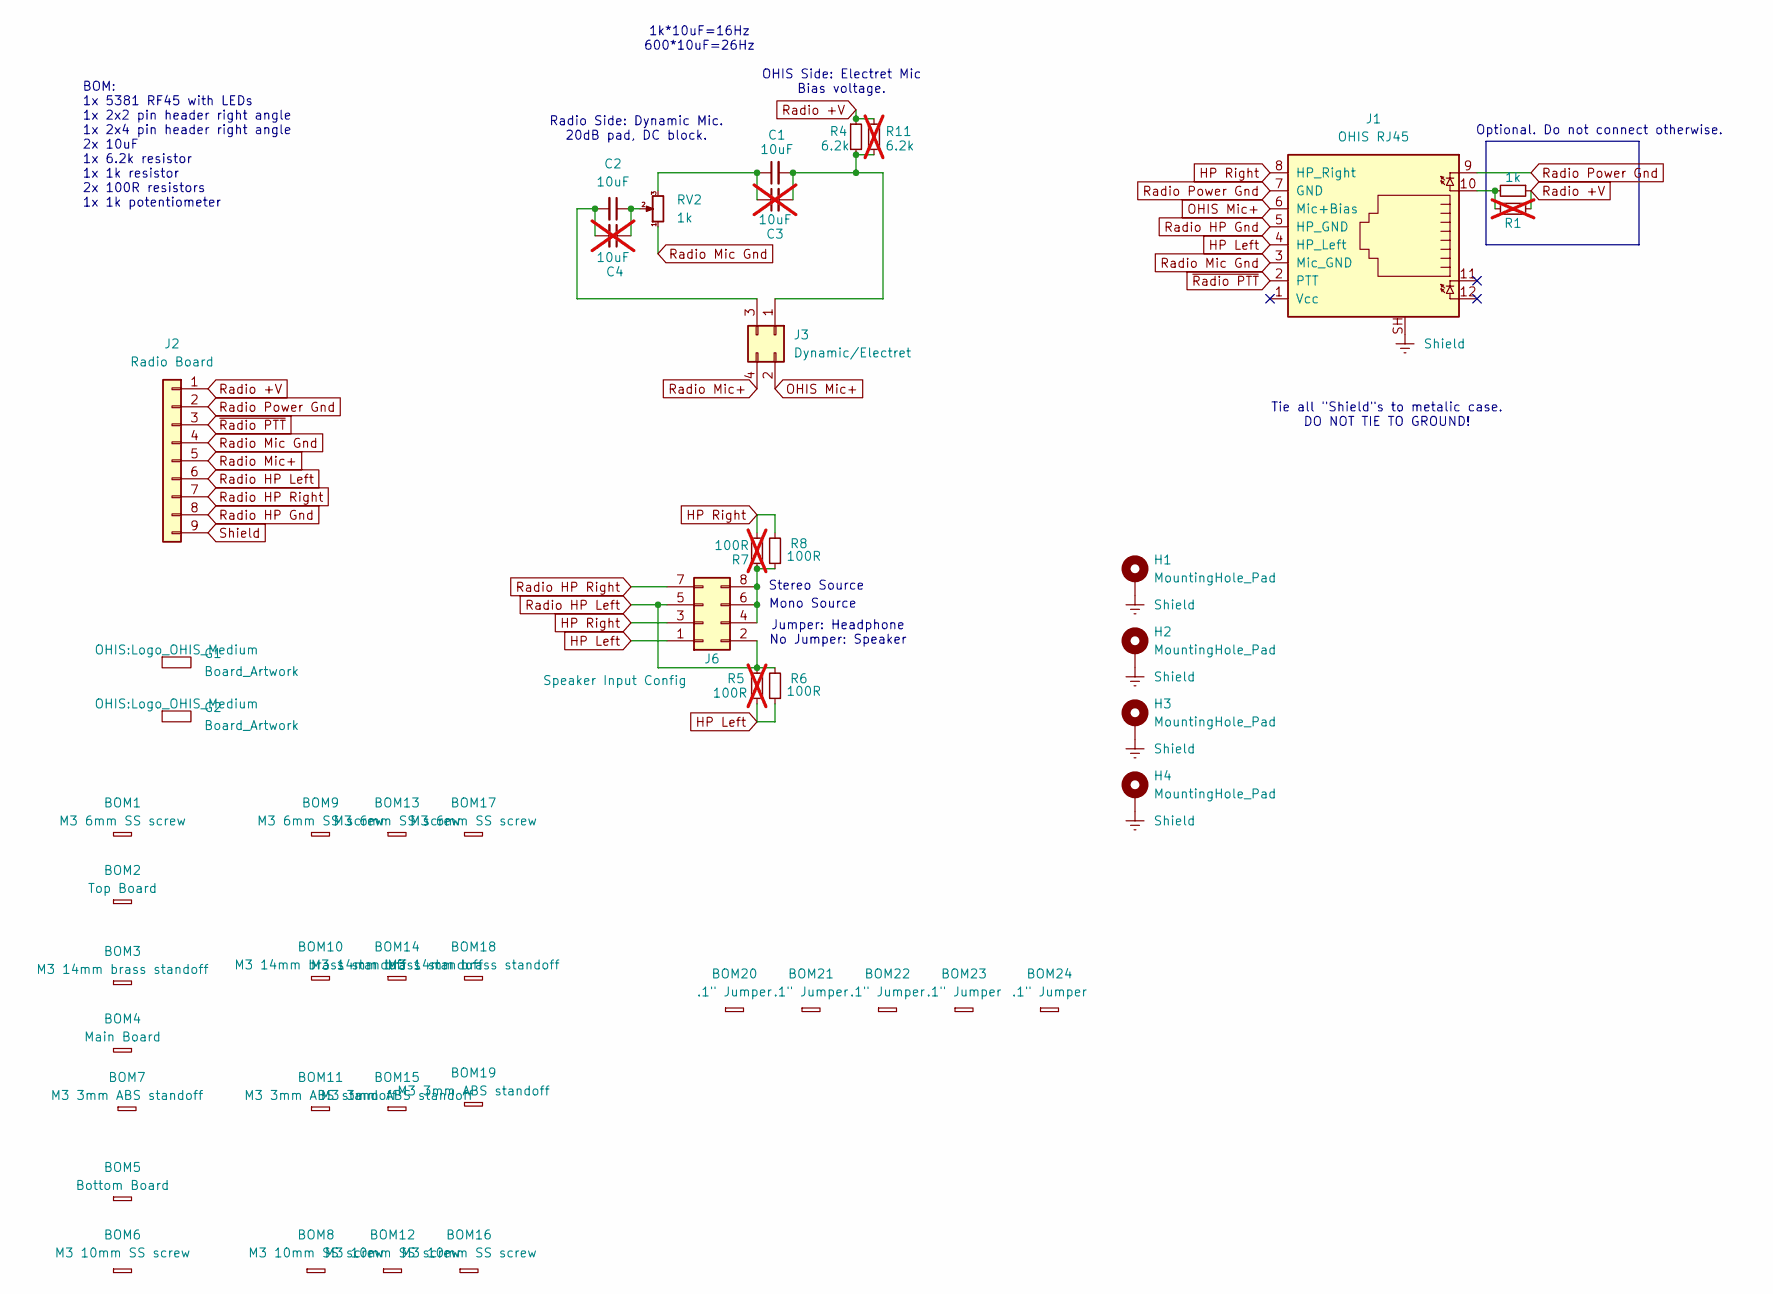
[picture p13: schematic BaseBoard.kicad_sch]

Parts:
BOM1, BOM9, BOM13, BOM17: M3 6mm SS screw; BOM_Item; Part Number M3 6mm SS screw
BOM2: Top Board; BOM_Item
BOM3, BOM10, BOM14, BOM18: M3 14mm brass standoff; BOM_Item; Part Number M3 14mm brass standoff
BOM4: Main Board; BOM_Item
BOM5: Bottom Board; BOM_Item
BOM6, BOM8, BOM12, BOM16: M3 10mm SS screw; BOM_Item; Part Number M3 10mm SS screw
BOM7, BOM11, BOM15, BOM19: M3 3mm ABS standoff; BOM_Item; Part Number M3 3mm ABS standoff
BOM20, BOM21, BOM22, BOM23, BOM24: .1" Jumper; BOM_Item; Part Number .1" Pin Jumper
C1, C2: 10uF; C_Disc_D4.7mm_W2.5mm_P5.00mm; Part Number FG28X5R1E106MRT06
C3, C4: 10uF; C_1206_3216Metric; not fitted
G1, G2: Board_Artwork; Logo_OHIS_Medium
H1, H2, H3, H4: MountingHole_Pad; MountingHole_3.2mm_M3_Pad
J1: OHIS RJ45; RJ45_Amphenol_RJHSE538X; Part Number RJHSE-5381
J2: Radio Board; Conn_B2B-RA_2.54mm_9pin_LtoR
J3: Dynamic/Electret; PinHeader_2x02_P2.54mm_Horizontal; Part Number .1" 3x40 right angle 2.54mm Pin Header
J6: Speaker Input Config; PinHeader_2x04_P2.54mm_Horizontal; Part Number .1" 3x40 right angle 2.54mm Pin Header; LCSC C9139
R1: 1k; R_Axial_DIN0207_L6.3mm_D2.5mm_P7.62mm_Horizontal; Part Number CFR-12JB-52-1K
R4: 6.2k; R_Axial_DIN0207_L6.3mm_D2.5mm_P7.62mm_Horizontal; Part Number CFR-12JB-52-6K2
R5, R7: 100R; R_1206_3216Metric; not fitted
R6, R8: 100R; R_Axial_DIN0207_L6.3mm_D2.5mm_P7.62mm_Horizontal; Part Number CFR-12JB-52-100R
R11: 6.2k; R_1206_3216Metric; not fitted
R12: 1k; R_1206_3216Metric; not fitted
RV2: 1k; Potentiometer_Piher_PT-6-H_Horizontal; Part Number N6-S25T0C-102

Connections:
HP Left: J1.4 (HP_Left), J6.1, R5.1, R6.1
HP Right: J1.8 (HP_Right), J6.3, R7.1, R8.2
unnamed: C1.1, C3.1, RV2.3
unnamed: C2.1, C4.1, RV2.2
unnamed: J1.10, R1.2, R12.2
unnamed: C1.2, C3.2, J3.1, R4.2, R11.2
unnamed: C2.2, C4.2, J3.3
unnamed: J6.4, J6.6, J6.8, R7.2, R8.1
OHIS Mic+: J1.6 (Mic+Bias), J3.2
Radio +V: J2.1, R1.1, R4.1, R11.1, R12.1
Radio HP Gnd: J1.5 (HP_GND), J2.8
Radio HP Left: J2.6, J6.2, J6.5, R5.2, R6.2
Radio HP Right: J2.7, J6.7
Radio Mic Gnd: J1.3 (Mic_GND), J2.4, RV2.1
Radio Mic+: J2.5, J3.4
Radio Power Gnd: J1.7 (GND), J1.9, J2.2
Shield: H1.1, H2.1, H3.1, H4.1, J1.SH, J2.9
~Radio PTT: J1.2 (PTT), J2.3

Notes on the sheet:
Stereo Source
OHIS Side: Electret Mic Bias voltage.
Mono Source
Radio Side: Dynamic Mic. 20dB pad, DC block.
Tie all "Shield"s to metalic case. DO NOT TIE TO GROUND!
1k*10uF=16Hz 600*10uF=26Hz
BOM: 1x 5381 RF45 with LEDs 1x 2x2 pin header right angle 1x 2x4 pin header right angle 2x 10uF 1x 6.2k resistor 1x 1k resistor 2x 100R resistors 1x 1k potentiometer
Jumper: Headphone No Jumper: Speaker
Optional. Do not connect otherwise.

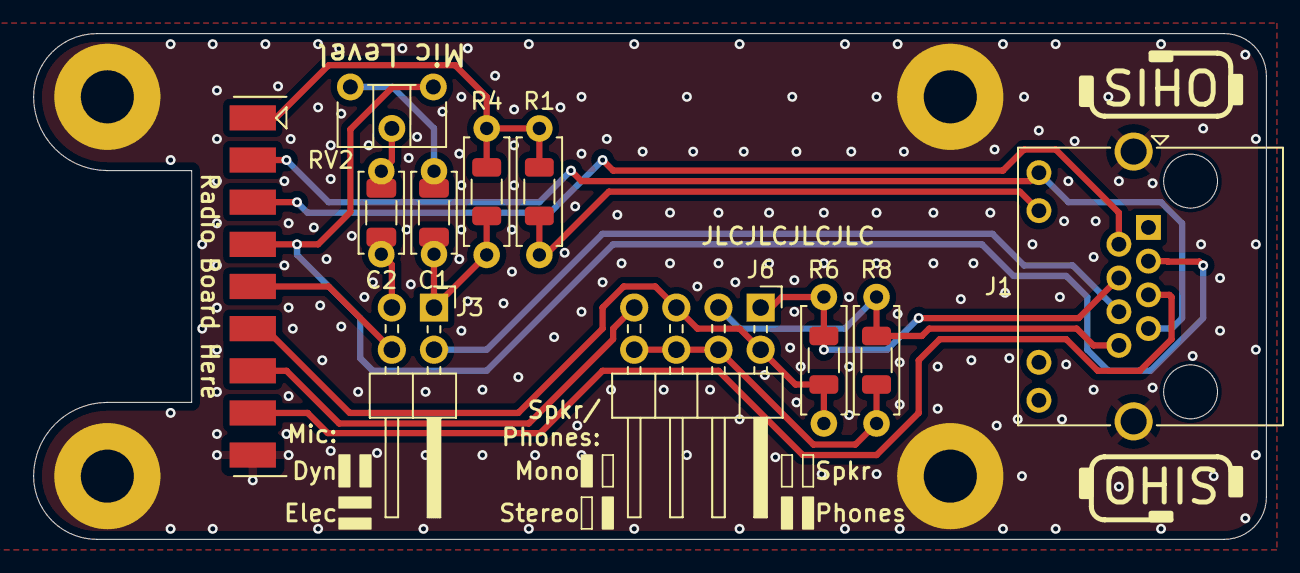
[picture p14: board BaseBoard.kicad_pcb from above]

Board: 2 copper layers, 74.3 x 30.5 mm, 47 parts (0 on the bottom side), 18 nets.

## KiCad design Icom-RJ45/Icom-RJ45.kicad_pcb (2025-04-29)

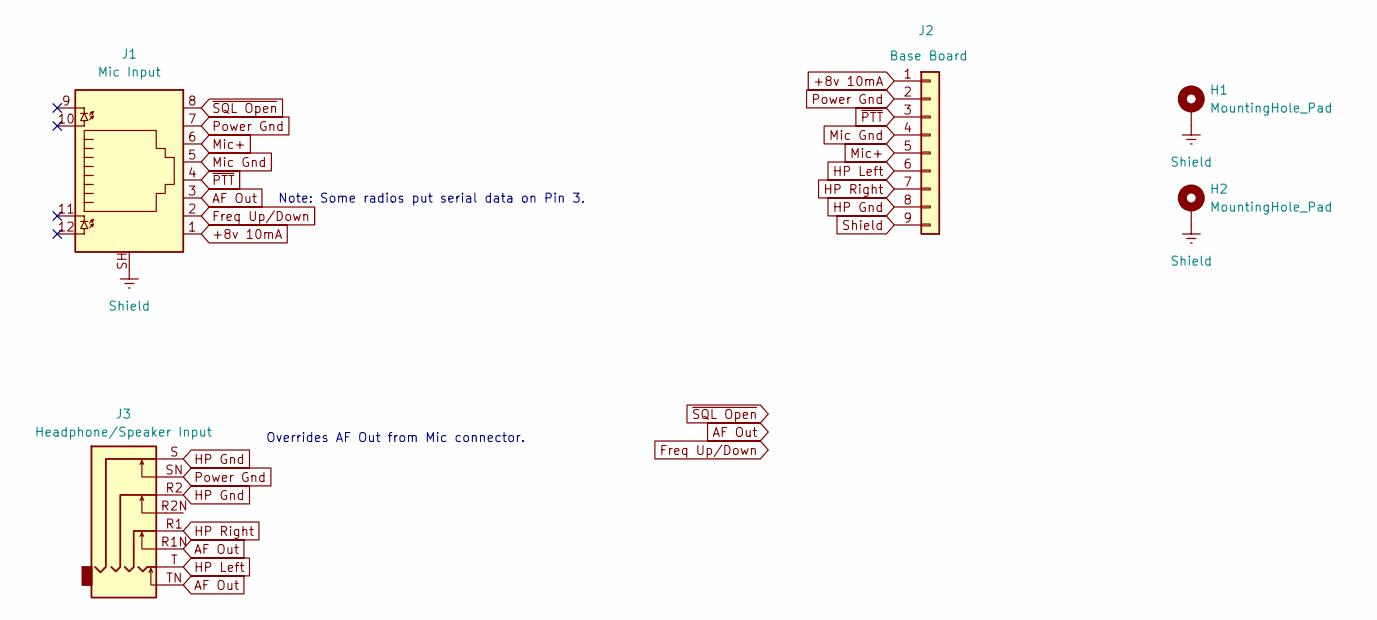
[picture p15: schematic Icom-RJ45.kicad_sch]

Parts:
H1, H2: MountingHole_Pad; MountingHole_3.2mm_M3_Pad
J1: Mic Input; RJ45_Amphenol_RJHSE538X
J2: Base Board; Conn_B2B-RA_2.54mm_9pin_RtoL
J3: Headphone/Speaker Input; Conn_3.5mm-PJ-393_SMT-C668609_TH-C145811

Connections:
+8v 10mA: J1.1, J2.1
AF Out: J1.3, J3.R1N, J3.TN
Freq Up/Down: J1.2
HP Gnd: J2.8, J3.R2, J3.S
HP Left: J2.6, J3.T
HP Right: J2.7, J3.R1
Mic Gnd: J1.5, J2.4
Mic+: J1.6, J2.5
Power Gnd: J1.7, J2.2, J3.SN
Shield: H1.1, H2.1, J1.SH, J2.9
~PTT: J1.4, J2.3
~SQL Open: J1.8

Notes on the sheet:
Note: Some radios put serial data on Pin 3.
Overrides AF Out from Mic connector.

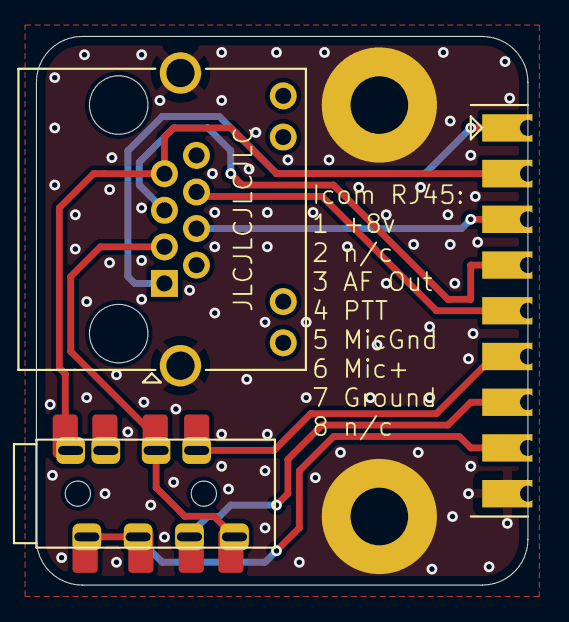
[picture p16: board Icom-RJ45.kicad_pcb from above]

Board: 2 copper layers, 27.3 x 30.5 mm, 6 parts (1 on the bottom side), 10 nets.

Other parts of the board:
G1: Logo_OHIS; Logo_OHIS_Medium

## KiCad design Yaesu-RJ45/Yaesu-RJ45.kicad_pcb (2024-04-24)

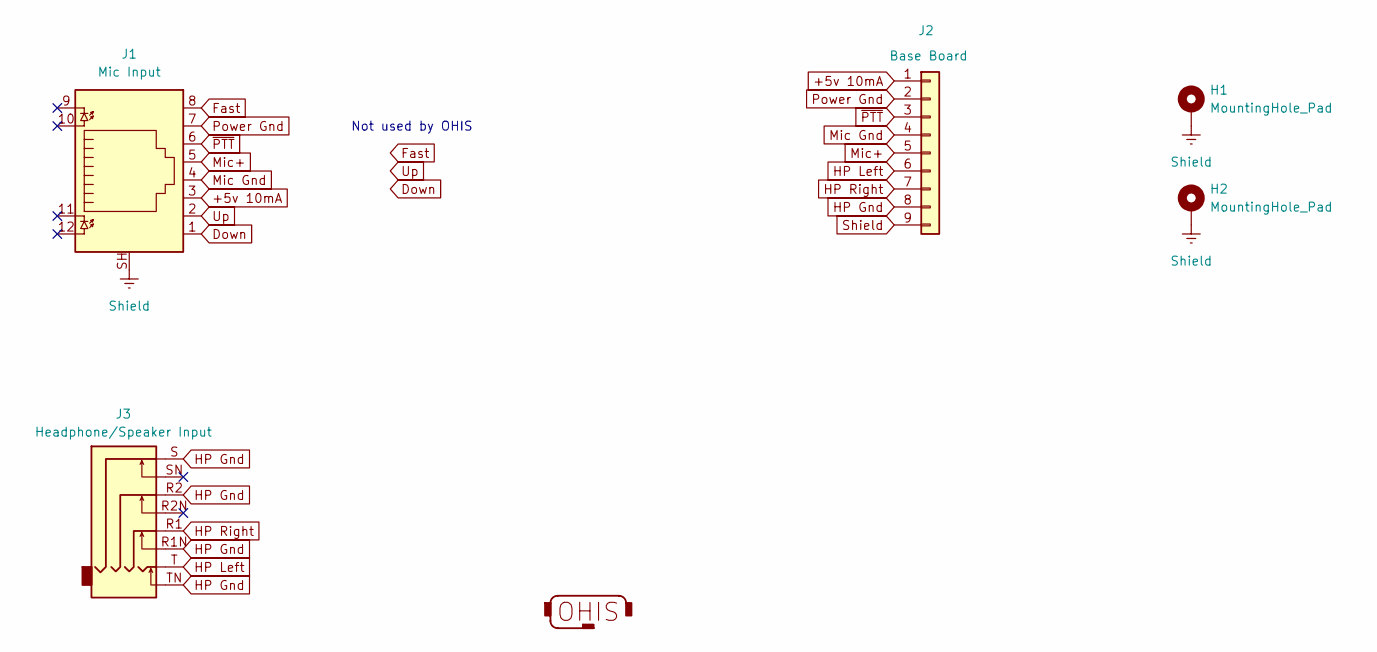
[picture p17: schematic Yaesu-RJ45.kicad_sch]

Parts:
G1: Logo_OHIS; Logo_OHIS_Medium
H1, H2: MountingHole_Pad; MountingHole_3.2mm_M3_Pad
J1: Mic Input; RJ45_Amphenol_RJHSE538X
J2: Base Board; Conn_B2B-RA_2.54mm_Castelated_9pin_RtoL
J3: Headphone/Speaker Input; Conn_3.5mm-PJ-393_SMT-C668609_TH-C145811

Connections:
+5v 10mA: J1.3, J2.1
Down: J1.1
Fast: J1.8
HP Gnd: J2.8, J3.R1N, J3.R2, J3.S, J3.TN
HP Left: J2.6, J3.T
HP Right: J2.7, J3.R1
Mic Gnd: J1.4, J2.4
Mic+: J1.5, J2.5
Power Gnd: J1.7, J2.2
Shield: H1.1, H2.1, J1.SH, J2.9
Up: J1.2
~PTT: J1.6, J2.3

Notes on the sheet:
Not used by OHIS

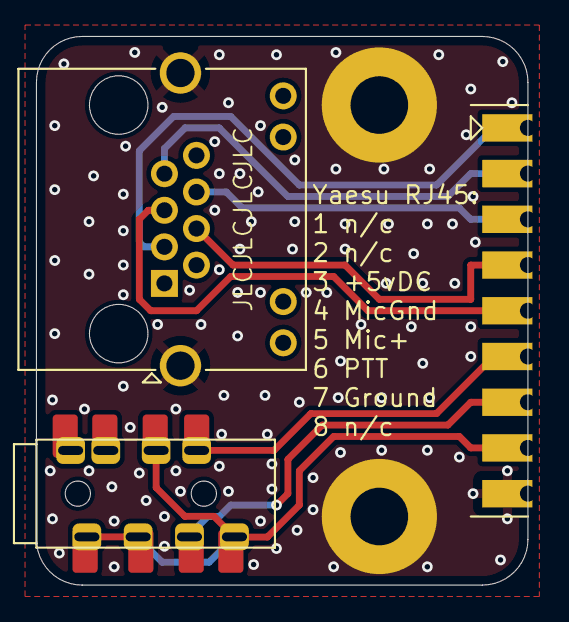
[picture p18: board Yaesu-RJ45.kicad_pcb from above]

Board: 2 copper layers, 27.3 x 30.5 mm, 6 parts (1 on the bottom side), 9 nets.

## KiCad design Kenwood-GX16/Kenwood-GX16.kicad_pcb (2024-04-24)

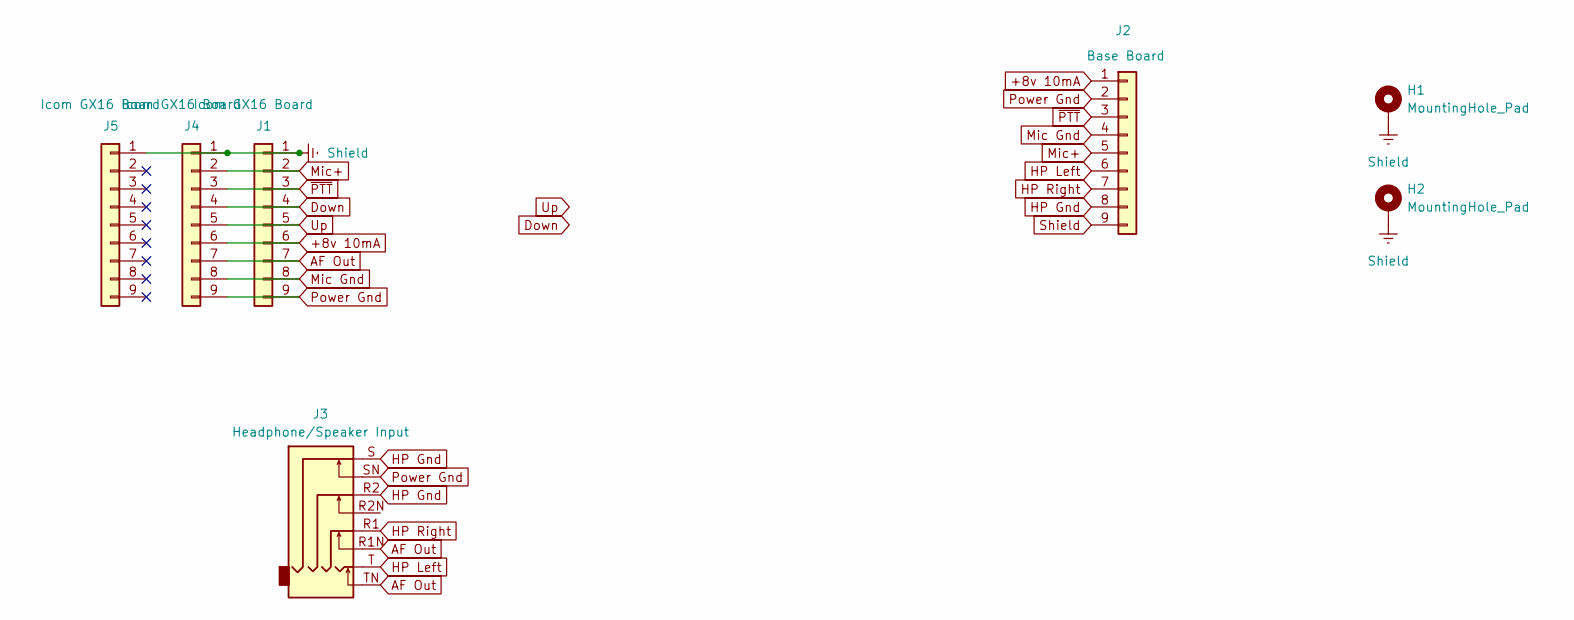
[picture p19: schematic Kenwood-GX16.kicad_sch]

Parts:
H1, H2: MountingHole_Pad; MountingHole_3.2mm_M3_Pad
J1: Icom GX16 Board; Conn_B2B-RA_2.54mm_9pin_RtoL
J2: Base Board; Conn_B2B-RA_2.54mm_Castelated_9pin_RtoL
J3: Headphone/Speaker Input; Conn_3.5mm-PJ-393_SMT-C668609_TH-C145811
J4, J5: Icom GX16 Board; Conn_B2B-RA_2.54mm_9pin_LtoR

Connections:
+8v 10mA: J1.6, J2.1, J4.6
AF Out: J1.7, J3.R1N, J3.TN, J4.7
Down: J1.4, J4.4
HP Gnd: J2.8, J3.R2, J3.S
HP Left: J2.6, J3.T
HP Right: J2.7, J3.R1
Mic Gnd: J1.8, J2.4, J4.8
Mic+: J1.2, J2.5, J4.2
Power Gnd: J1.9, J2.2, J3.SN, J4.9
Shield: H1.1, H2.1, J1.1, J2.9, J4.1, J5.1
Up: J1.5, J4.5
~PTT: J1.3, J2.3, J4.3



Board: 2 copper layers, 27.3 x 38.1 mm, 7 parts (2 on the bottom side), 12 nets.

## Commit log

2024-04-05 Initial swag at a very simple Icom radio adapter. #1
    [Icom.kicad_pcb, Icom.kicad_sch]
2024-04-05 Adding a Yaesu example. #1
    [Yaesu.kicad_pcb, Yaesu.kicad_sch]
2024-04-05 Icom pinout references. Renamed Earth to Shield.
    [Icom.kicad_sch]
2024-04-05 Yaesu mic pinout references. #1
    [Yaesu.kicad_sch]
2024-04-05 Simple Kenwood Radio Adapter. #1
    [Kenwood.kicad_pcb, Kenwood.kicad_sch]
2024-04-16 Printing schematics to PDFs.
2024-04-18 See #1, for Icom. Not happy with this, but committing for record.
    [Icom.kicad_pcb, Icom.kicad_sch]
2024-04-19 For #1. Looks much more like the User Adapter.
    [Icom.kicad_pcb, Icom.kicad_sch]
2024-04-22 Kenwood laid out more similarly to the User Adapter. #1
    [Icom.kicad_pcb, Icom.kicad_sch, Kenwood.kicad_pcb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]
2024-04-22 Moving to common BaseBoard architecture. #1
    [BaseBoard.kicad_pcb, BaseBoard.kicad_sch, Icom-RJ45.kicad_pcb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]
2024-04-24 Happy with BaseBoard and Icom-RJ45. Working on Icom-GX16 #1
    [BaseBoard.kicad_pcb, BaseBoard.kicad_sch, Icom-GX16.kicad_pcb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]
2024-04-24 Icom-GX16 added. Also GX16 riser board. #1
    [GX16-8P-Horizontal Slot Test.kicad_pcb, GX16-8P-Horizontal Slot Test.kicad_sch, GX16-8P-Horizontal.kicad_pcb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]
2024-04-24 Splitting Yaesu/ out into three directories: RJ45, GX16, 6p6c #1
    [Yaesu.kicad_pcb, Yaesu.kicad_sch]
2024-04-24 Yaesu and Kenwood radio boards. #1 As ordered prototypes v1.0a
    [Kenwood-GX16.kicad_pcb, Kenwood-GX16.kicad_sch, Kenwood-RJ45.kicad_pcb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]
2024-12-03 I can't find 1.6mm washers/spacers ANYWHERE. So I make my own. #1
    [ShimBoard.kicad_pcb, ShimBoard.kicad_sch]
2024-12-03 Updated BOM parts, among other things. Sorry, it's been a while. #1
    [BaseBoard.kicad_pcb, BaseBoard.kicad_sch]
2024-12-03 Added parts list, and current status, to README.md #1
2025-04-29 Added an Interactive BOM for the Base Board assembly.
    [BaseBoard.kicad_pcb, BaseBoard.kicad_sch, Icom-RJ45.kicad_pcb]
2025-05-28 Radio Adapter v2. Active, isolated. RF protection. As ordered 2025-05-29
    [Main-Board.kicad_pcb, Main-Board.kicad_sch, Pinout - DIY.kicad_pcb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]
2025-05-28 radio adapter v2 front and back panels.
    [Back-Panel.kicad_pcb, Back-Panel.kicad_sch, Front-Panel.kicad_pcb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]

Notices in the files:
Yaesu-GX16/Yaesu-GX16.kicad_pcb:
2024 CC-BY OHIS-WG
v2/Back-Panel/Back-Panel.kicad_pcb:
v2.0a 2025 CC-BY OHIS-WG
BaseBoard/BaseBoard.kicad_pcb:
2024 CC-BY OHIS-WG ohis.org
